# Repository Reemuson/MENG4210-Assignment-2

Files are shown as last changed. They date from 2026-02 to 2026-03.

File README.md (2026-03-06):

<p align="center" width="100%">
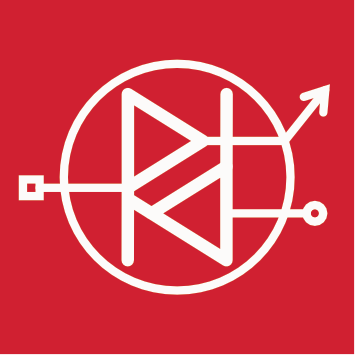
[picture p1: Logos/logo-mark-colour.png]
  
</p>

<h1 align="center">INPUT PROTECTION</h1>

<p align="center" width="100%">
  <a href="https://github.com/Reemuson/MENG4210-Assignment-2/actions/workflows/ci.yaml">
    
  </a>
</p>

<p align="center" width="100%">
    
</p>

***

<p align="center">
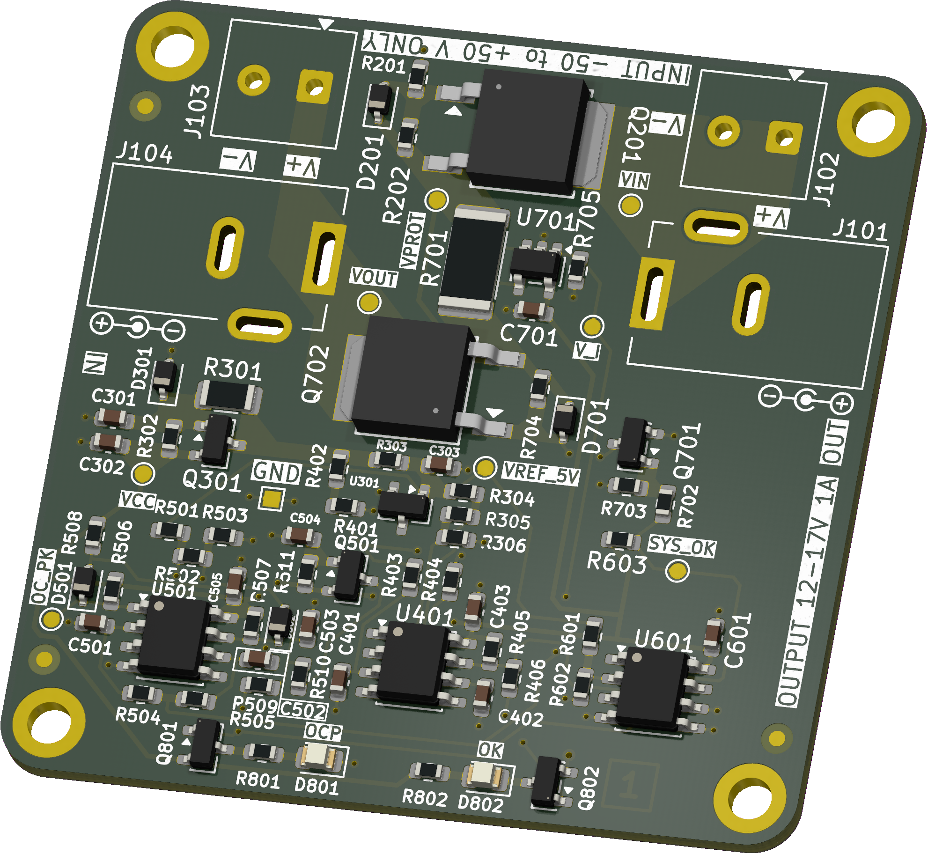
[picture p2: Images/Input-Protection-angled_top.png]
3D Top Angled
  
&nbsp; &nbsp; &nbsp; &nbsp;
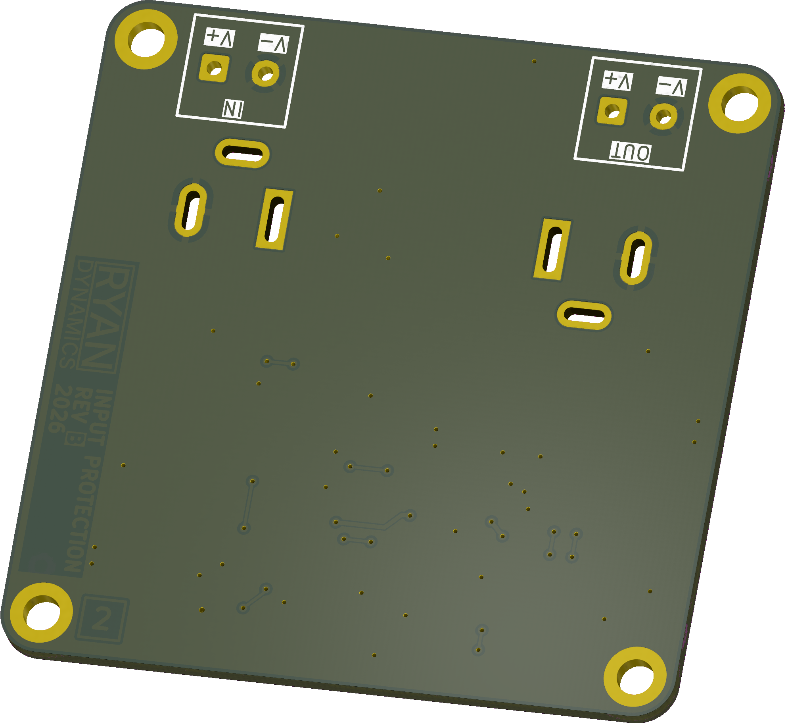
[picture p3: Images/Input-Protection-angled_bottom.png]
3D Bottom Angled
  
</p>

***

## SPECIFICATIONS

| Parameter | Value | 
| --- | --- |
| Dimensions | 50.0 × 50.0 mm |

***

## DIRECTORY STRUCTURE

    .
    ├─ Computations       # Misc calculations
    ├─ HTML               # HTML files for generated webpage
    ├─ Images             # Pictures and renders
    │
    ├─ kibot_resources    # External resources for KiBot
    │  ├─ colors          # Color theme for KiCad
    │  ├─ fonts           # Fonts used in the project
    │  ├─ scripts         # External scripts used with KiBot
    │  └─ templates       # Templates for KiBot generated reports
    │
    ├─ kibot_yaml         # KiBot YAML config files
    ├─ KiRI               # KiRI (PCB diff viewer) files
    │
    ├─ lib                # KiCad footprint and symbol libraries
    │  ├─ 3d_models       # Component 3D models
    │  ├─ lib_fp          # Footprint libraries
    │  └─ lib_sym         # Symbol libraries
    │
    ├─ Logos              # Logos
    │
    ├─ Manufacturing      # Assembly and fabrication documents
    │  ├─ Assembly        # Assembly documents (BoM, pos, notes)
    │  │
    │  └─ Fabrication     # Fabrication documents (ZIP, notes)
    │     ├─ Drill Tables # CSV drill tables
    │     └─ Gerbers      # Gerbers
    │
    ├─ Report             # Reports for ERC/DRC
    ├─ Schematic          # PDF of schematic
    ├─ Templates          # Title block templates
    ├─ Testing
    │  └─ Testpoints      # Testpoints tables      
    │
    └─ Variants           # Outputs for assembly variants

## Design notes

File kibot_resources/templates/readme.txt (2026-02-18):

<p align="center" width="100%">
  
</p>

<h1 align="center">${BOARD_NAME}</h1>

<p align="center" width="100%">
  <a href="${GIT_URL}/actions/workflows/ci.yaml">
    CI Badge
  </a>
</p>

<p align="center" width="100%">
    
</p>

***

<p align="center">
  3D Top Angled
&nbsp; &nbsp; &nbsp; &nbsp;
  3D Bottom Angled
</p>

***

## SPECIFICATIONS

| Parameter | Value | 
| --- | --- |
| Dimensions | ${bb_w_mm} × ${bb_h_mm} mm |

***

## DIRECTORY STRUCTURE

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

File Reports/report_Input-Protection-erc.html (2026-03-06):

Logo

(https://github.com/INTI-CMNB/KiBot/) | ERC report for Input-Protection
| Schematic: Input-Protection Revision: 1.0.0 Date: 2026-03-06T14:02:25+0000 KiCad Version: 9.0.7 | Errors: 0 Warnings: 18 Total: 18

Sheet / (Input-Protection.kicad_sch)

Type | Description | Details
footprint_link_issues | The current configuration does not include the footprint library 'RD-Testpoints'. | @(0.5715 mm, 0.6223 mm): Symbol TP201 [TestPoint]
lib_symbol_mismatch | Symbol 'BC846' doesn't match copy in library 'Transistor_BJT' | @(1.1811 mm, 0.762 mm): Symbol Q301 [BC846]
footprint_link_issues | The current configuration does not include the footprint library 'RD-Testpoints'. | @(1.2065 mm, 0.8763 mm): Symbol TP301 [TestPoint]
footprint_link_issues | The current configuration does not include the footprint library 'RD-Testpoints'. | @(1.4859 mm, 0.762 mm): Symbol TP302 [TestPoint]
lib_symbol_mismatch | Symbol 'BC856' doesn't match copy in library 'Transistor_BJT' | @(1.6637 mm, 1.4859 mm): Symbol Q801 [BC856]
footprint_link_issues | The current configuration does not include the footprint library 'RD-Testpoints'. | @(1.0414 mm, 2.1717 mm): Symbol TP501 [TestPoint]
lib_symbol_mismatch | Symbol 'BC846' doesn't match copy in library 'Transistor_BJT' | @(1.9431 mm, 1.4859 mm): Symbol Q802 [BC846]
footprint_link_issues | The current configuration does not include the footprint library 'RD-Testpoints'. | @(2.4892 mm, 0.9525 mm): Symbol TP701 [TestPoint]
lib_symbol_mismatch | Symbol 'BC856' doesn't match copy in library 'Transistor_BJT' | @(1.5621 mm, 2.3368 mm): Symbol Q501 [BC856]
lib_symbol_mismatch | Symbol 'BC846' doesn't match copy in library 'Transistor_BJT' | @(2.6797 mm, 0.9779 mm): Symbol Q701 [BC846]
footprint_link_issues | The current configuration does not include the footprint library 'RD-Testpoints'. | @(2.794 mm, 1.397 mm): Symbol TP702 [TestPoint]
footprint_link_issues | The current configuration does not include the footprint library 'RD-Testpoints'. | @(3.4671 mm, 0.6096 mm): Symbol TP101 [TestPoint]
footprint_link_issues | The current configuration does not include the footprint library 'RD-Testpoints'. | @(3.302 mm, 1.27 mm): Symbol TP901 [TestPoint]
footprint_link_issues | The current configuration does not include the footprint library 'RD-Testpoints'. | @(3.7338 mm, 0.6096 mm): Symbol TP102 [TestPoint]
footprint_link_issues | The current configuration does not include the footprint library 'RD-Symbols-Silkscreen'. | @(3.81 mm, 1.5875 mm): Symbol ID901 [BOARD_STACKUP_MARKER]
lib_symbol_issues | The current configuration does not include the symbol library 'Ryan-Dynamics' | @(3.81 mm, 1.5875 mm): Symbol ID901 [BOARD_STACKUP_MARKER]

Sheet /SCHEMATIC/ (Schematic.kicad_sch)

Type | Description | Details
multiple_net_names | Both VPROT and SHUNT_HI are attached to the same items; VPROT will be used in the netlist | @(0.6985 mm, 0.6096 mm): Global Label 'VPROT' @(2.2606 mm, 0.6858 mm): Label 'SHUNT_HI'
multiple_net_names | Both VSUPPLY and SHUNT_LO are attached to the same items; VSUPPLY will be used in the netlist | @(2.4892 mm, 0.6096 mm): Global Label 'VSUPPLY' @(2.3368 mm, 0.6858 mm): Label 'SHUNT_LO'

Generated by KiBot (https://github.com/INTI-CMNB/KiBot/) v1.8.6

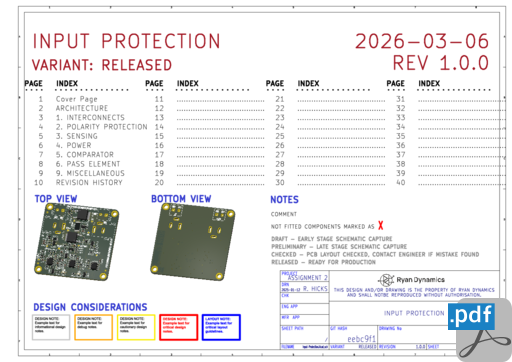
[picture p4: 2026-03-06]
HTML/images/cat_pdf_schematic_Input-Protection-schematic.png

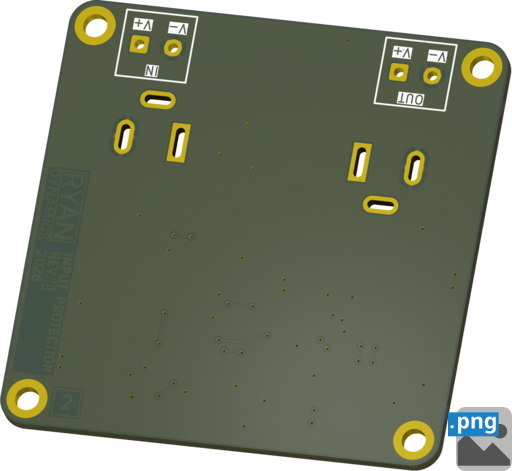
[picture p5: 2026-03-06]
HTML/images/cat_png_3d_viewer_angled_bottom_Input-Protection-angled_bottom.png

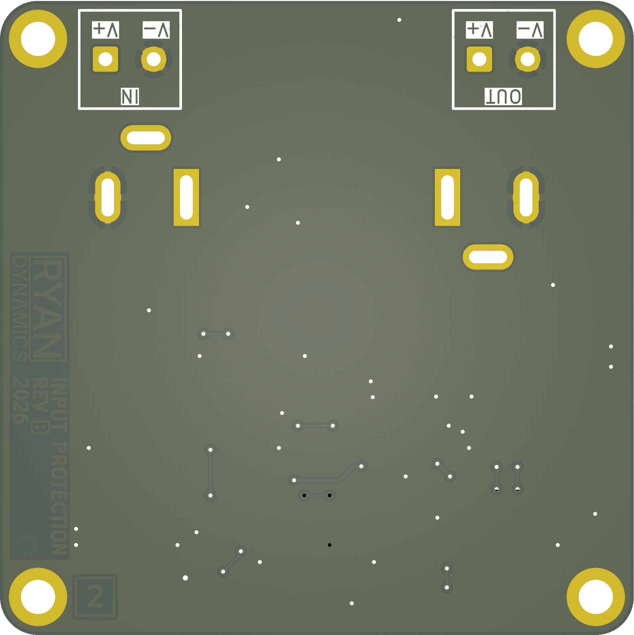
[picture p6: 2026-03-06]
Images/Input-Protection-bottom.png

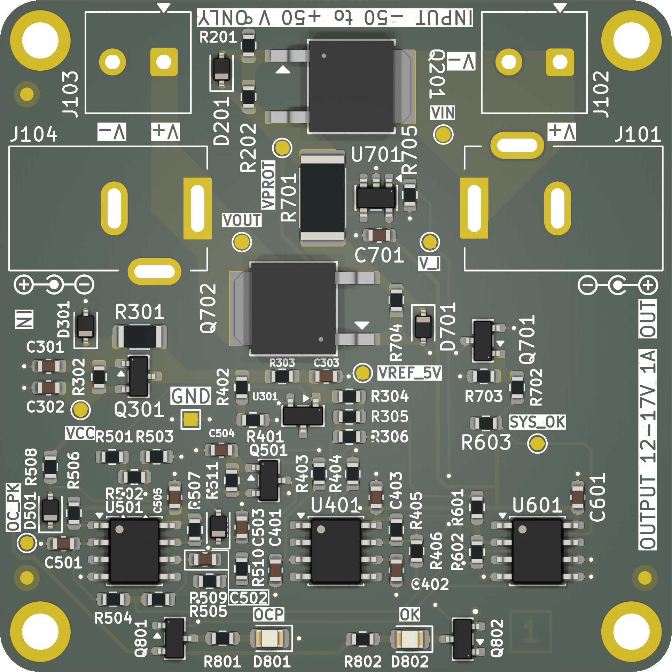
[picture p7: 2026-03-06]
Images/Input-Protection-top.png

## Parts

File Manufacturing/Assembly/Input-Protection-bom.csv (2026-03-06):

Row | Quantity Per PCB | References | Value | Datasheet | Footprint | Description | Manufacturer | MPN | Supplier | SPN | Notes
1 | 4 | C303 C401 C402 C501 | 10n | https://mm.digikey.com/Volume0/opasdata/d220001/medias/docus/931/C_Series_GeneralAppl_B11.pdf | C_0603_1608Metric | CAP CER 0.01UF 50V X7R 0603 | TPK | C1608X7R1H103KT
2 | 5 | C301 C403 C505 C601 C701 | 100n | https://mm.digikey.com/Volume0/opasdata/d220001/medias/docus/931/C_Series_GeneralAppl_B11.pdf | C_0603_1608Metric | CAP CER 0.1UF 16V X7R 0603 | TPK | C1608X7R1C104KT
3 | 3 | C302 C502 C504 | 1u | https://mm.digikey.com/Volume0/opasdata/d220001/medias/docus/931/C_Series_GeneralAppl_B11.pdf | C_0603_1608Metric | CAP CER 1UF 6.3V X7R 0603 | TPK | C1608X5R0J105KT
4 | 1 | C503 | 4.7u | https://mm.digikey.com/Volume0/opasdata/d220001/medias/docus/931/C_Series_GeneralAppl_B11.pdf | C_0603_1608Metric | CAP CER 4.7UF 6.3V X5R 0603 | TPK | C1608X5R0J475MT
5 | 2 | D501 D502 | 1N4148WS | https://diotec.com/request/datasheet/1n4148ws.pdf | D_SOD-323 | DIODE STANDARD 75V 150MA SOD323F | Diotec Semiconductor | 1N4148WS |  |  | Fast switching diode
6 | 2 | D201 D701 | D3Z10BF-7 | https://www.diodes.com/assets/Datasheets/D3ZxVxBF.pdf | D_SOD-323 | DIODE ZENER 10V 400MW SOD323F | Diodes Incorporated | D3Z10BF-7 |  |  | VZ = 10 V, suitable for input over-voltage clamping
7 | 1 | D801 | LED | https://optoelectronics.liteon.com/upload/download/DS-22-99-0150/LTST-C170KRKT.pdf | LED_0805_2012Metric | LED RED CLEAR SMD | Lite-On Inc. | LTST-C170KRKT | DigiKey | 160-1415-1-ND | Any low power red 0805 LED
8 | 1 | D802 | LED | https://optoelectronics.liteon.com/upload/download/DS22-2000-073/LTST-C170KGKT.pdf | LED_0805_2012Metric | LED RED CLEAR SMD | Lite-On Inc. | LTST-C170KGKT | DigiKey | 160-1414-1-ND | Any low power green 0805 LED
9 | 1 | D301 | MM3Z5V6 | https://www.diodes.com/assets/Datasheets/D3ZxVxBF.pdf | D_SOD-323 | DIODE ZENER 5V6 400MW SOD323F | Diotec | MM3Z5V6 |  |  | VZ = 5V6, for VCC reference
10 | 2 | J102 J103 | EBWA-02-B | https://app.adam-tech.com/products/download/data_sheet/204240/ebwa-xx-b-data-sheet.pdf | TerminalBlock_Phoenix_MKDS-1-2-3.81_1x02_P3.81mm_Horizontal | EURO BLOCK 2P | Adam Tech | EBWA-02-B
11 | 2 | J101 J104 | KLDX-0202-B | https://www.kycon.com/Catalog_PDF/KLDX_0202.pdf | BarrelJack_Kycon_KLDX-0202-xC_Horizontal | CONN PWR JACK 2.5X5.5MM SOLDER | Kycon Inc | KLDX-0202-B
12 | 3 | Q301 Q701 Q802 | BC846 | https://assets.nexperia.com/documents/data-sheet/BC846X-Q_SER.pdf | SOT-23 | TRANS NPN 65V 0.1A TO-236AB | Nexperia USA Inc. | BC846 |  |  | VCEO > 65 V for 50 V rail, IC small, used as gate pull-down switch
13 | 2 | Q501 Q801 | BC856 | https://www.onsemi.com/pub/Collateral/BC860-D.pdf | SOT-23 | 0.1A Ic, 65V Vce, PNP Transistor, SOT-23
14 | 2 | Q201 Q702 | MCU18P10Y-TP | https://www.mccsemi.com/pdf/Products/MCU18P10Y(DPAK).pdf | DPAK_MCC | MOSFET P-CH 100V 18A DPAK | MCC (Micro Commercial Components) | MCU18P10Y-TP |  |  | VDS > 100 V, ID > 2 A, P-channel device suitable for high-side switching
15 | 1 | R701 | 20m | https://www.vishay.com/docs/30100/wsl.pdf | R_2512_6332Metric | RES 0.02 OHM 1% 1W 2512 | Vishay Dale | WSL2512R0200FEA | DigiKey | WSLG-.02CT-ND | Current sense shunt, sets OCP trip (~1 A). Ideally should be <100m
16 | 4 | R403 R404 R504 R510 | 1k | https://www.analogtechnologies.com/document/New_Resistor_Kits.pdf | R_0603_1608Metric | RES 1K OHM 1% 1/10W 0603 | Analog Technologies
17 | 2 | R801 R802 | 2.49k | https://www.analogtechnologies.com/document/New_Resistor_Kits.pdf | R_0603_1608Metric | RES 2.49K OHM 1% 1/10W 0603 | Analog Technologies
18 | 5 | R405 R506 R507 R603 R702 | 10k | https://www.analogtechnologies.com/document/New_Resistor_Kits.pdf | R_0603_1608Metric | RES 10K OHM 1% 1/10W 0603 | Analog Technologies
19 | 1 | R301 | 12.1k | https://www.analogtechnologies.com/document/New_Resistor_Kits.pdf | R_1206_3216Metric | RES 12.1K OHM 1% 1/4W 1206 | Analog Technologies
20 | 1 | R705 | 15k | https://www.analogtechnologies.com/document/New_Resistor_Kits.pdf | R_0603_1608Metric | RES 15K OHM 1% 1/10W 0603 | Analog Technologies
21 | 1 | R601 | 18.2k | https://www.analogtechnologies.com/document/New_Resistor_Kits.pdf | R_0603_1608Metric | RES 18.2K OHM 1% 1/10W 0603 | Analog Technologies
22 | 1 | R401 | 22.1k | https://www.analogtechnologies.com/document/New_Resistor_Kits.pdf | R_0603_1608Metric | RES 22.1K OHM 1% 1/10W 0603 | Analog Technologies
23 | 1 | R503 | 30.1k | https://www.analogtechnologies.com/document/New_Resistor_Kits.pdf | R_0603_1608Metric | RES 30.1K OHM 1% 1/10W 0603 | Analog Technologies
24 | 2 | R303 R602 | 33.2k | https://www.analogtechnologies.com/document/New_Resistor_Kits.pdf | R_0603_1608Metric | RES 33.2K OHM 1% 1/10W 0603 | Analog Technologies
25 | 2 | R305 R505 | 49.9k | https://www.analogtechnologies.com/document/New_Resistor_Kits.pdf | R_0603_1608Metric | RES 49.9K OHM 1% 1/10W 0603 | Analog Technologies
26 | 8 | R201 R202 R302 R406 R509 R511 R703 R704 | 100k | https://www.analogtechnologies.com/document/New_Resistor_Kits.pdf | R_0603_1608Metric | RES 100K OHM 1% 1/10W 0603 | Analog Technologies
27 | 2 | R306 R502 | 121k | https://www.analogtechnologies.com/document/New_Resistor_Kits.pdf | R_0603_1608Metric | RES 121K OHM 1% 1/10W 0603 | Analog Technologies
28 | 1 | R402 | 200k | https://www.analogtechnologies.com/document/New_Resistor_Kits.pdf | R_0603_1608Metric | RES 200K OHM 1% 1/10W 0603 | Analog Technologies
29 | 1 | R304 | 332k | https://www.analogtechnologies.com/document/New_Resistor_Kits.pdf | R_0603_1608Metric | RES 332K OHM 1% 1/10W 0603 | Analog Technologies
30 | 1 | R501 | 357k | https://www.analogtechnologies.com/document/New_Resistor_Kits.pdf | R_0603_1608Metric | RES 357K OHM 1% 1/10W 0603 | Analog Technologies
31 | 1 | R508 | 432k | https://www.analogtechnologies.com/document/New_Resistor_Kits.pdf | R_0603_1608Metric | RES 432K OHM 1% 1/10W 0603 | Analog Technologies
32 | 1 | U701 | INA169NA/3K | http://www.ti.com/lit/ds/symlink/ina169.pdf | SOT-23-5 | IC CURRENT MONITOR 0.5% SOT23-5 | Texas Instruments | INA169NA/3K |  |  | Transconductance of 1mA/V
33 | 3 | U401 U501 U601 | LM393 | http://www.ti.com/lit/ds/symlink/lm393.pdf | SOIC-8_3.9x4.9mm_P1.27mm | Low-Power, Low-Offset Voltage, Dual Comparators, DIP-8/SOIC-8/TO-99-8
34 | 1 | U301 | LM4040N-5.0 | http://www.ti.com/lit/ds/symlink/lm4040-n.pdf | SOT-23 | IC VREF SHUNT 0.5% SOT23-3 | Texas Instruments | LM4040CIM3-5.0/NOPB |  |  | VREF = 5.0 V, low temperature coefficient, suitable for precision threshold VREF

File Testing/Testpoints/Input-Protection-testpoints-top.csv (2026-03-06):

Ref. | Net | X [mm] | Y [mm]
TP101 | VIN | 33.00 | 40.00
TP102 | VOUT | 18.00 | 32.00
TP201 | VPROT | 21.00 | 39.00
TP301 | VCC | 6.00 | 19.50
TP302 | VREF_5V | 27.00 | 22.25
TP501 | OC_PEAK_FAULT | 2.00 | 9.60
TP701 | SYS_OK | 40.00 | 17.00
TP702 | V_I | 32.00 | 32.00
TP901 | GND | 14.20 | 18.80

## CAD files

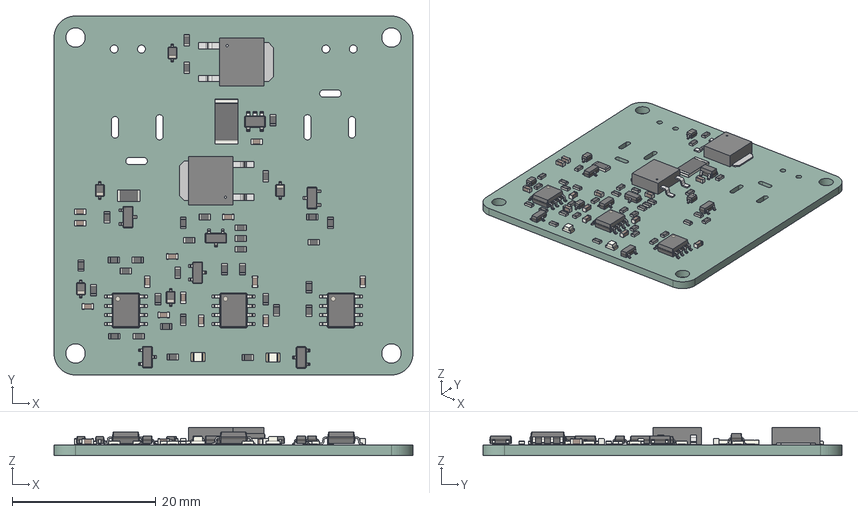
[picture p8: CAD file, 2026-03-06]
3D/Input-Protection.step
50.0 x 50.0 x 3.96 mm
R_0603_1608Metric x 33
C_0603_1608Metric x 13
D_SOD-323 x 5
SOT-23 x 6
R_1206_3216Metric
DPAK_MCC x 2
SOIC-8_3.9x4.9mm_P1.27mm x 3
LED_0805_2012Metric x 2
R_2512_6332Metric
SOT-23-5
kibot_4t420ams_PCB

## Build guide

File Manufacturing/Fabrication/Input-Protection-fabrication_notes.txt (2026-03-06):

FABRICATION NOTES (UNLESS OTHERWISE SPECIFIED)

1)	FABRICATE PER IPC-6012A CLASS 2.

2)	OUTLINE DEFINED IN SEPARATE GERBER FILE WITH
	"Edge_Cuts.GBR" SUFFIX.

3)	SEE SEPARATE DRILL FILES WITH ".DRL" SUFFIX 
	FOR HOLE LOCATIONS.

4)	SURFACE FINISH: ENIG

5)	SOLDERMASK ON BOTH SIDES OF THE BOARD SHALL 
	BE LPI, COLOR GREEN.

6)	SILK SCREEN LEGEND TO BE APPLIED PER LAYER 
	STACKUP USING WHITE NON-CONDUCTIVE EPOXY INK.

7)	VENDOR SHOULD FOLLOW ROHS COMPLIANT PROCESS 
	AND Pb FREE FOR MANUFACTURING

8)	PCB MATERIAL REQUIREMENTS:

	A.	FLAMMABILITY RATING MUST MEET OR EXCEED 
		UL94V-0 REQUIREMENTS.
	B.	Tg 170 C OR EQUIVALENT.
	C.	EQUIVALENT MATERIAL SHALL BE RoHS COMPLIANT, 
		HALOGEN FREE AND APPROVED BY RYAN DYNAMICS.

9)	DESIGN GEOMETRY MINIMUM FEATURE SIZES:

	BOARD SIZE			50.000 × 50.000 mm
	BOARD THICKNESS		1.590 mm
	TRACE WIDTH			0.200 mm
	TRACE TO TRACE		0.200 mm
	MIN. HOLE (PTH)		0.300 mm
	MIN. HOLE (NPTH)	N/A mm
	ANNULAR RING		0.150 mm
	COPPER TO HOLE		0.254 mm
	COPPER TO EDGE		0.250 mm
	HOLE TO HOLE		0.254 mm

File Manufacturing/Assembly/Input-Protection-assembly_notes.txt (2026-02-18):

ASSEMBLY NOTES (UNLESS OTHERWISE SPECIFIED)

1)	DO NOT POPULATE PARTS ARE MARKED WITH A RED CROSS.

2)	DO NOT POPULATE PARTS ARE NOT PRESENT IN THE BOM.

3)	IF CONFLICTING INFORMATION IS FOUND BETWEEN THE ASSEMBLY
	FILE AND BOM, BOM SHOULD BE USED AS THE MAIN SOURCE.

4)	CONFORMAL COATING IS NOT REQUIRED.

5)	DOT IDENTIFIES PIN #1 LOCATION AND DEVICE ORIENTATION
	WHEN VIEWED FROM THE TOP.

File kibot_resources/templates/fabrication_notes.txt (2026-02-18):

FABRICATION NOTES (UNLESS OTHERWISE SPECIFIED)

1)	FABRICATE PER IPC-6012A CLASS 2.

2)	OUTLINE DEFINED IN SEPARATE GERBER FILE WITH
	"Edge_Cuts.GBR" SUFFIX.

3)	SEE SEPARATE DRILL FILES WITH ".DRL" SUFFIX 
	FOR HOLE LOCATIONS.

4)	SURFACE FINISH: ${pcb_finish_cap}

5)	SOLDERMASK ON BOTH SIDES OF THE BOARD SHALL 
	BE LPI, COLOR ${solder_mask_color_text_cap}.

6)	SILK SCREEN LEGEND TO BE APPLIED PER LAYER 
	STACKUP USING ${silk_screen_color_text_cap} NON-CONDUCTIVE EPOXY INK.

7)	VENDOR SHOULD FOLLOW ROHS COMPLIANT PROCESS 
	AND Pb FREE FOR MANUFACTURING

8)	PCB MATERIAL REQUIREMENTS:

	A.	FLAMMABILITY RATING MUST MEET OR EXCEED 
		UL94V-0 REQUIREMENTS.
	B.	Tg 170 C OR EQUIVALENT.
	C.	EQUIVALENT MATERIAL SHALL BE RoHS COMPLIANT, 
		HALOGEN FREE AND APPROVED BY ${COMPANY_cap}.

9)	DESIGN GEOMETRY MINIMUM FEATURE SIZES:

	BOARD SIZE			${bb_w_mm} × ${bb_h_mm} mm
	BOARD THICKNESS		${thickness_mm} mm
	TRACE WIDTH			${track_mm} mm
	TRACE TO TRACE		${clearance_mm} mm
	MIN. HOLE (PTH)		${drill_pth_real_mm} mm
	MIN. HOLE (NPTH)	${drill_npth_real_mm} mm
	ANNULAR RING		${oar_mm} mm
	COPPER TO HOLE		${c2h_mm} mm
	COPPER TO EDGE		${c2e_mm} mm
	HOLE TO HOLE		${h2h_mm} mm
#?stackup and impedance_controlled

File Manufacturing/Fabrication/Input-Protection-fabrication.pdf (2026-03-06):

# TOP FABRICATION (SCALE 1:1)

# INPUT PROTECTION FABRICATION DOCUMENT

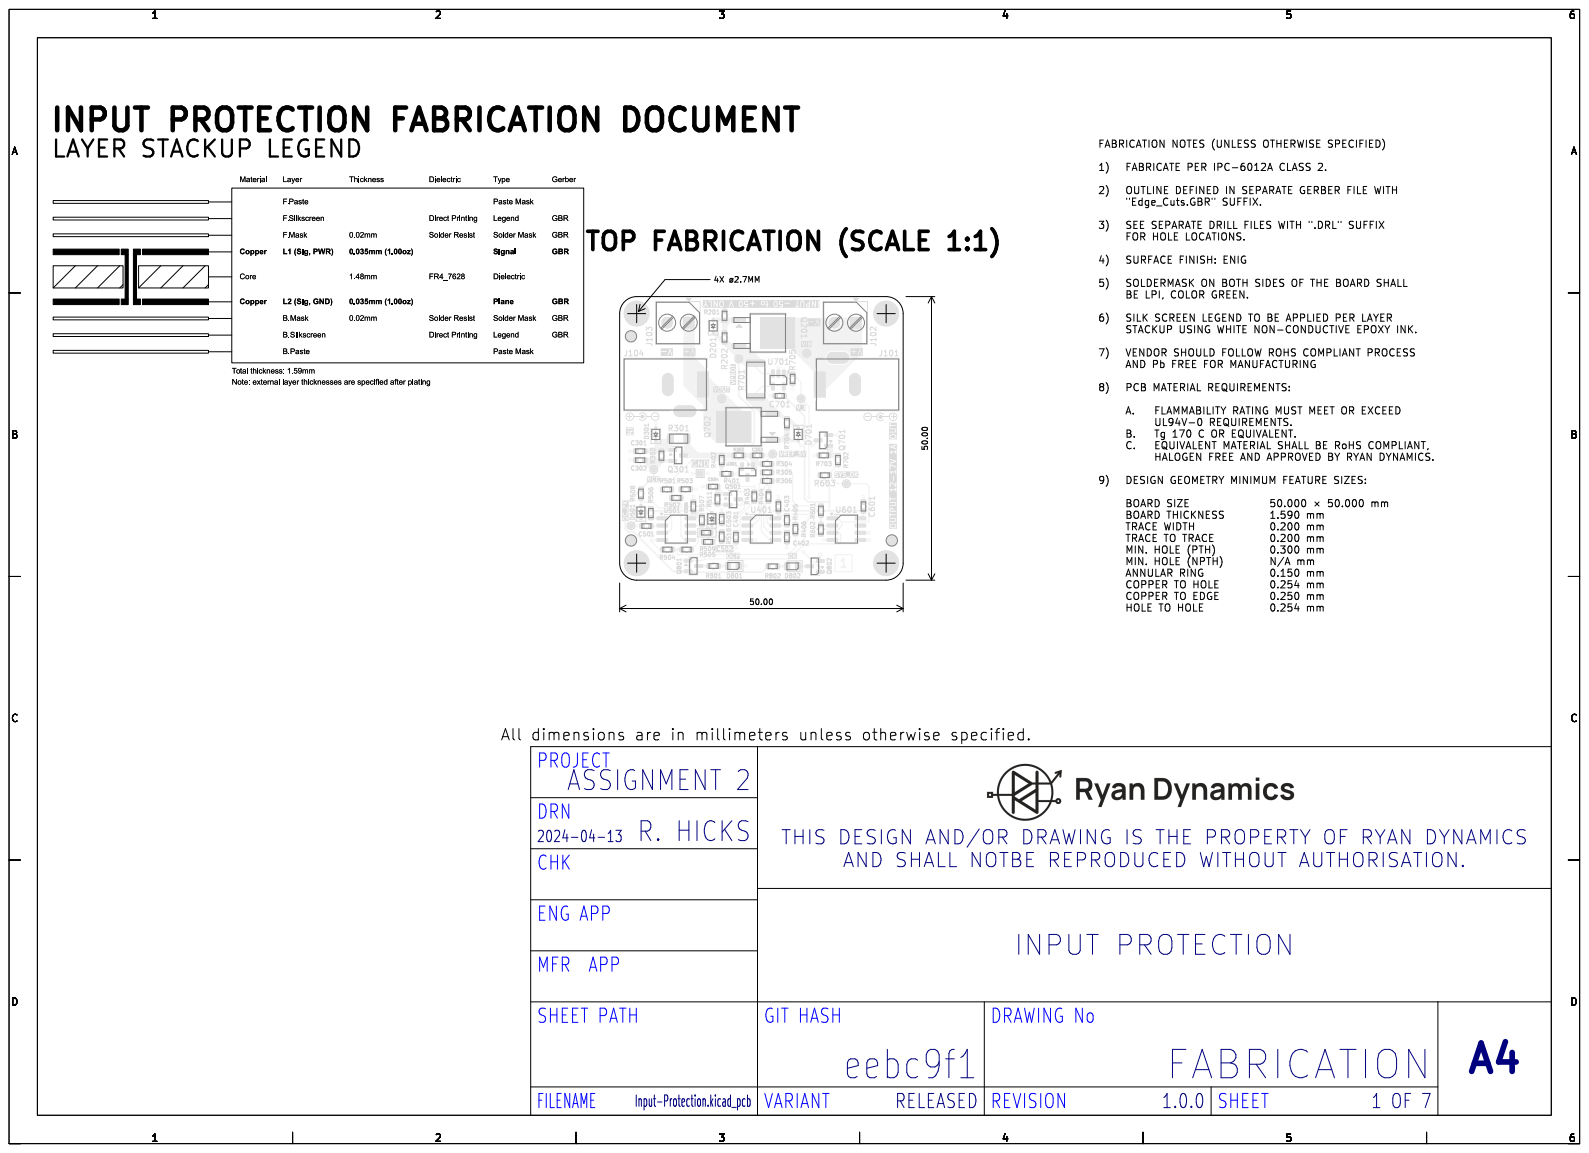
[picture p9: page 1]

FABRICATION NOTES (UNLESS OTHERWISE SPECIFIED)

1) FABRICATE PER IPC-6012A CLASS 2.

2) OUTLINE DEFINED IN SEPARATE GERBER FILE WITH
"Edge_Cuts.GBR" SUFFIX.

3) SEE SEPARATE DRILL FILES WITH ".DRL" SUFFIX
FOR HOLE LOCATIONS.

5) SOLDERMASK ON BOTH SIDES OF THE BOARD SHALL
BE LPI, COLOR GREEN.

6) SILK SCREEN LEGEND TO BE APPLIED PER LAYER
STACKUP USING WHITE NON-CONDUCTIVE EPOXY INK.

7) VENDOR SHOULD FOLLOW ROHS COMPLIANT PROCESS
AND Pb FREE FOR MANUFACTURING

A. FLAMMABILITY RATING MUST MEET OR EXCEED
UL94V-0 REQUIREMENTS.
B. Tg 170 C OR EQUIVALENT.
C. EQUIVALENT MATERIAL SHALL BE RoHS COMPLIANT,
HALOGEN FREE AND APPROVED BY RYAN DYNAMICS.

9) DESIGN GEOMETRY MINIMUM FEATURE SIZES:

BOARD SIZE 50.000 × 50.000 mm
BOARD THICKNESS 1.590 mm
TRACE WIDTH 0.200 mm
TRACE TO TRACE 0.200 mm
MIN. HOLE (PTH) 0.300 mm
MIN. HOLE (NPTH) N/A mm
ANNULAR RING 0.150 mm
COPPER TO HOLE 0.254 mm
COPPER TO EDGE 0.250 mm
HOLE TO HOLE 0.254 mm

All dimensions are in millimeters unless otherwise specified.
PROJECT
ASSIGNMENT 2
DRN
THIS DESIGN AND/OR DRAWING IS THE PROPERTY OF RYAN DYNAMICSAND SHALL NOTBE REPRODUCED WITHOUT AUTHORISATION.
CHK

BOTTOM | FABRICATION | (SCALE | 1:1)
INPUT | PROTECTION | FABRICATION DOCUMENT

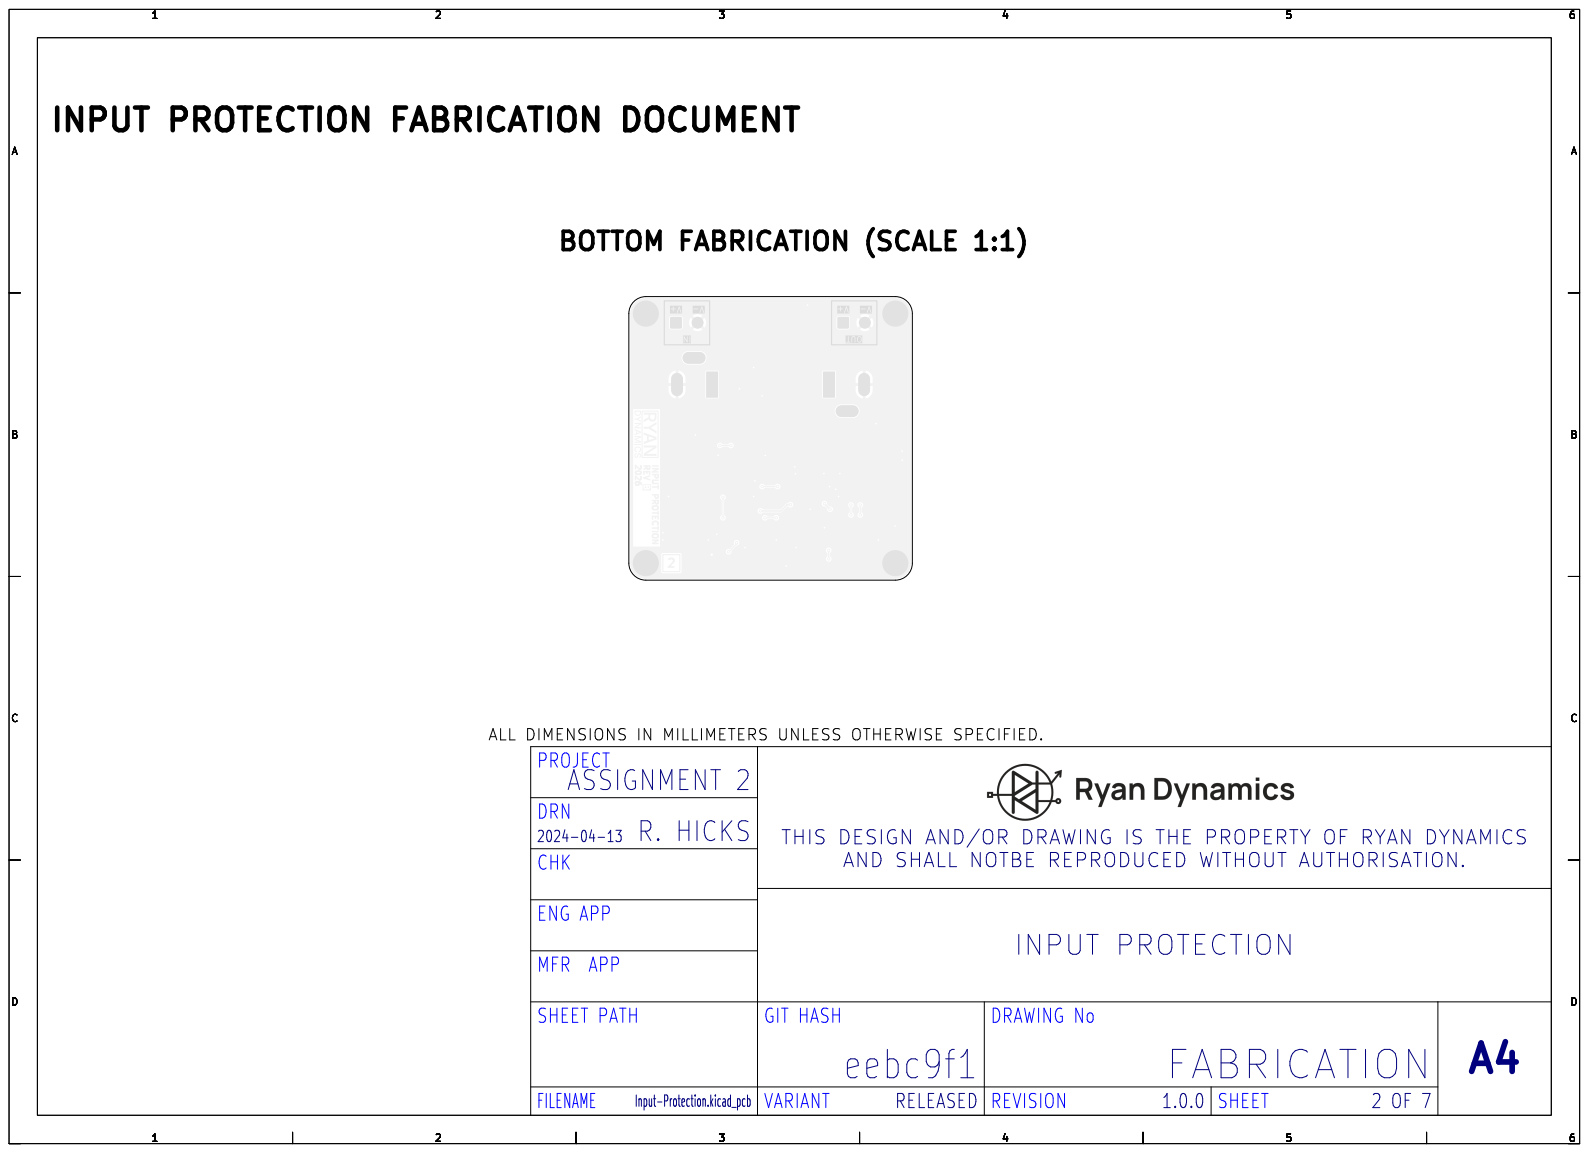
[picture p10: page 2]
DRAWING No; ASSIGNMENT 2; FABRICATION; PROJECT; INPUT; PROTECTION; ENG APP; 2024-04-13 CHK; GIT; HASH; SHEET; PATH; MFR; APP; DRN; R. HICKS; eebc9f1; THIS DESIGN AND/OR; DRAWING IS THE PROPERTY OF RYAN DYNAMICSAND SHALL NOTBE REPRODUCED WITHOUT AUTHORISATION.; ALL; DIMENSIONS; MILLIMETERS; UNLESS OTHERWISE; SPECIFIED.; REV; INPUT PROTECTION

DRILL | DRAWING L1 - L2 (SCALE | 1:1)
INPUT | PROTECTION | FABRICATION DOCUMENT

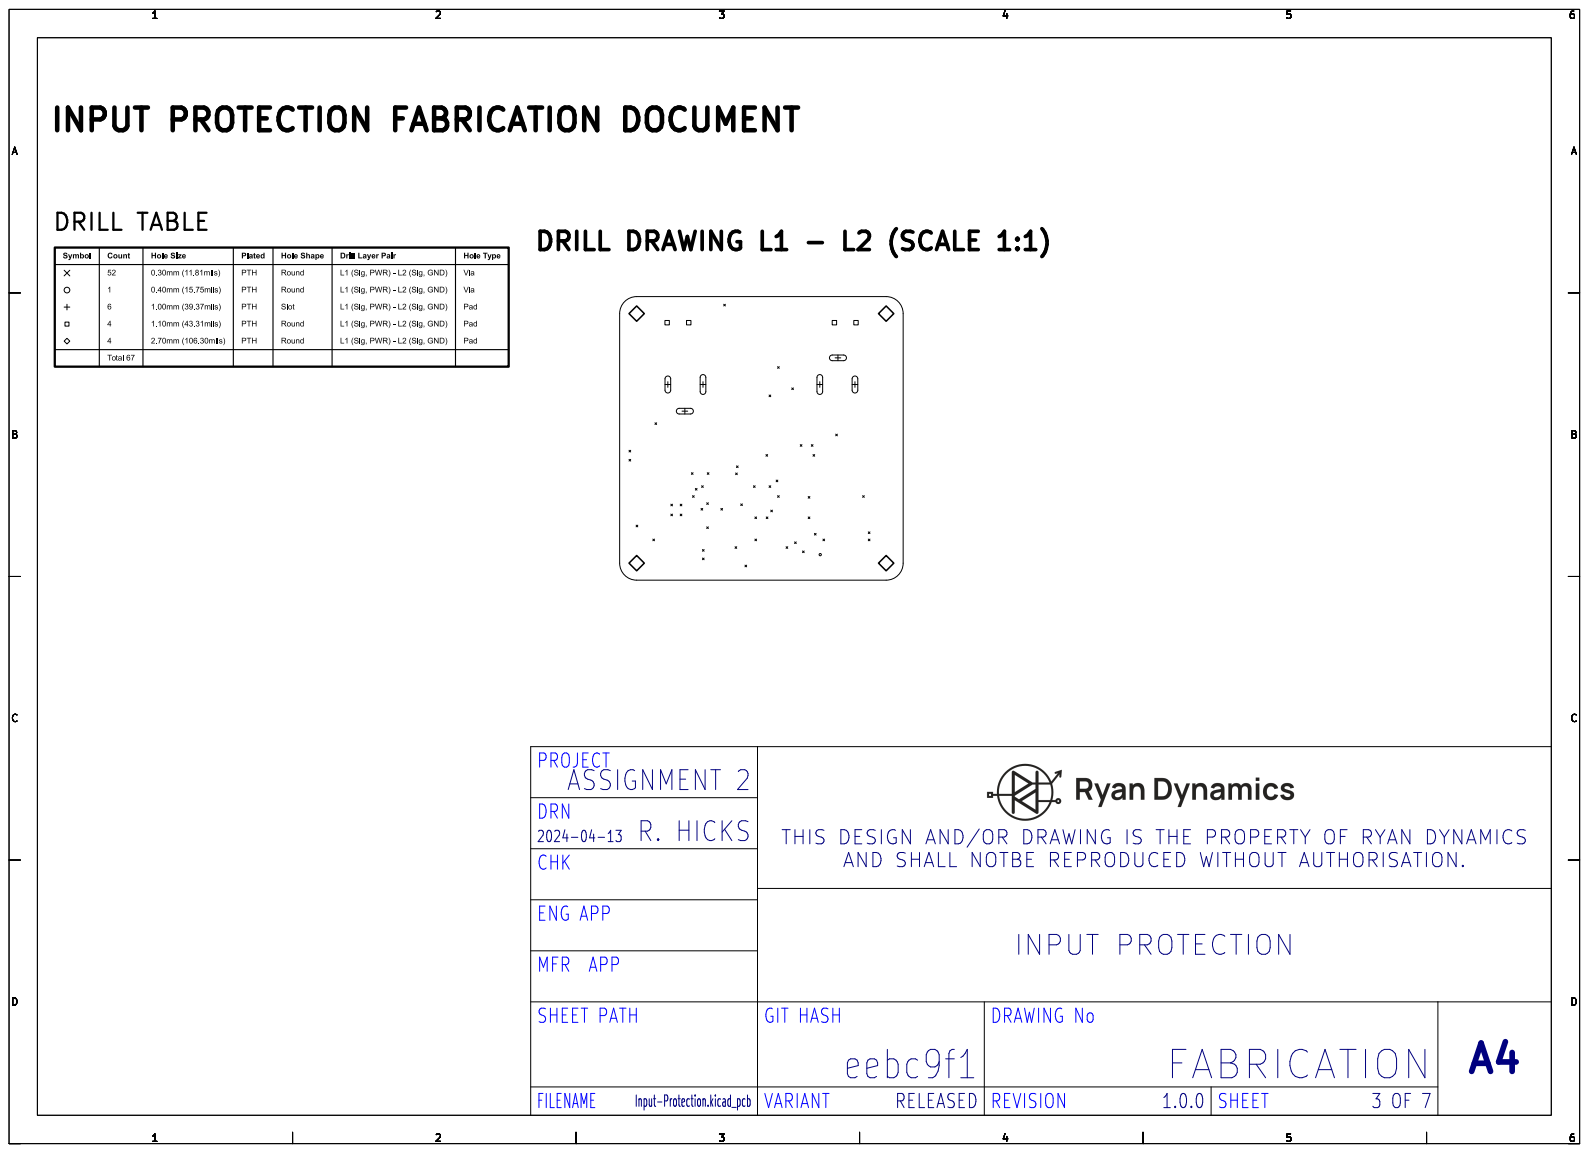
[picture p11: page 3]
DRAWING No; ASSIGNMENT 2; FABRICATION; PROJECT; INPUT; PROTECTION; ENG APP; 2024-04-13 CHK; GIT; HASH; SHEET; PATH; MFR; APP; DRN; R. HICKS; eebc9f1; THIS DESIGN AND/OR; DRAWING IS THE PROPERTY OF RYAN DYNAMICSAND SHALL NOTBE REPRODUCED WITHOUT AUTHORISATION.; DRILL TABLE

# TOP TEST POINTS (SCALE 1:1)

# INPUT PROTECTION FABRICATION DOCUMENT

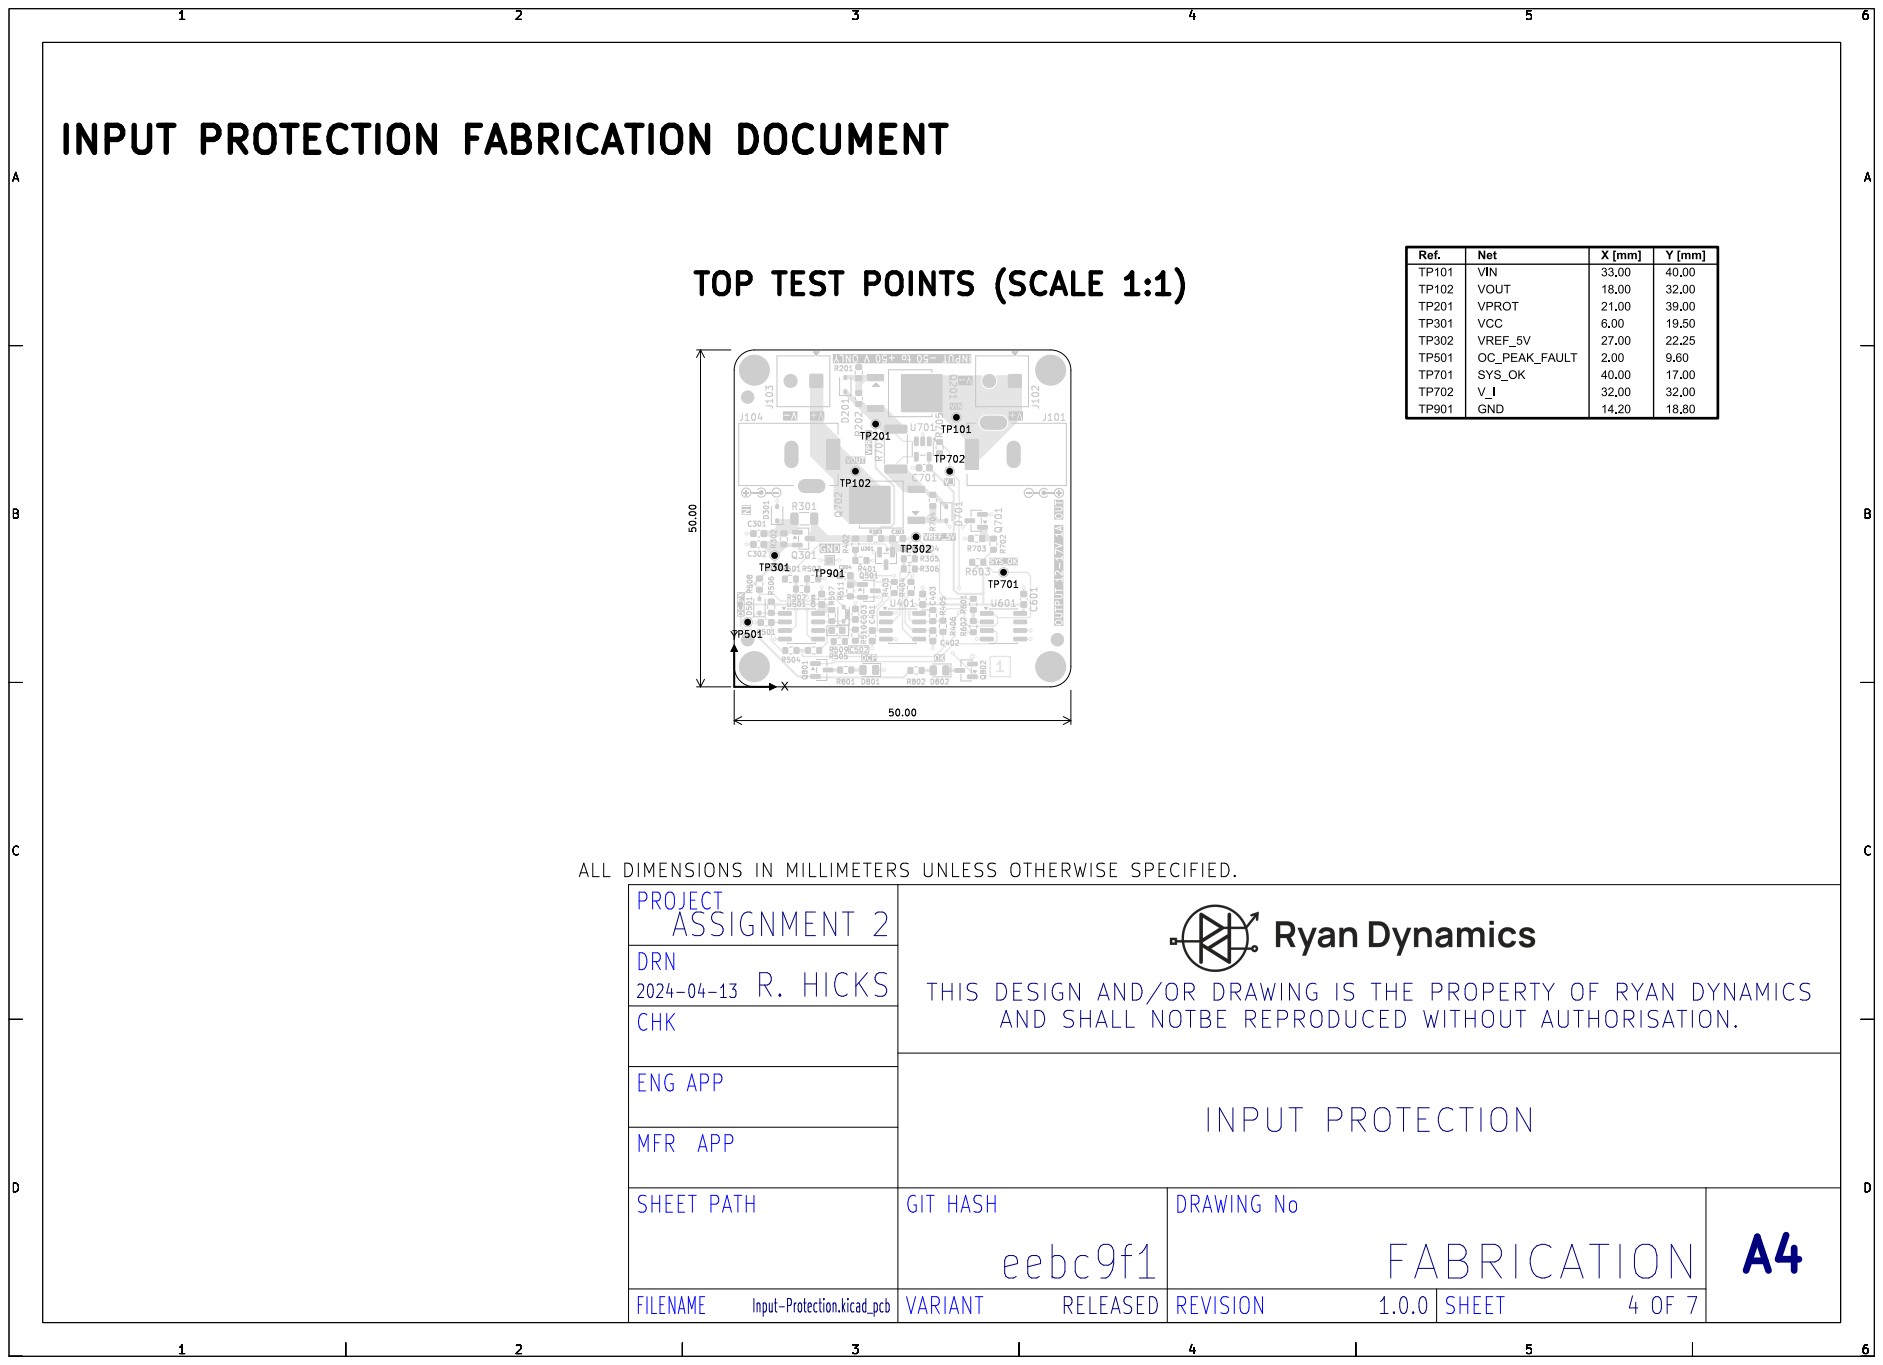
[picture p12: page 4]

PROJECT
ASSIGNMENT 2
DRN
THIS DESIGN AND/OR DRAWING IS THE PROPERTY OF RYAN DYNAMICSAND SHALL NOTBE REPRODUCED WITHOUT AUTHORISATION.
CHK

BOTTOM | TEST POINTS (SCALE | 1:1)
INPUT | PROTECTION | FABRICATION DOCUMENT

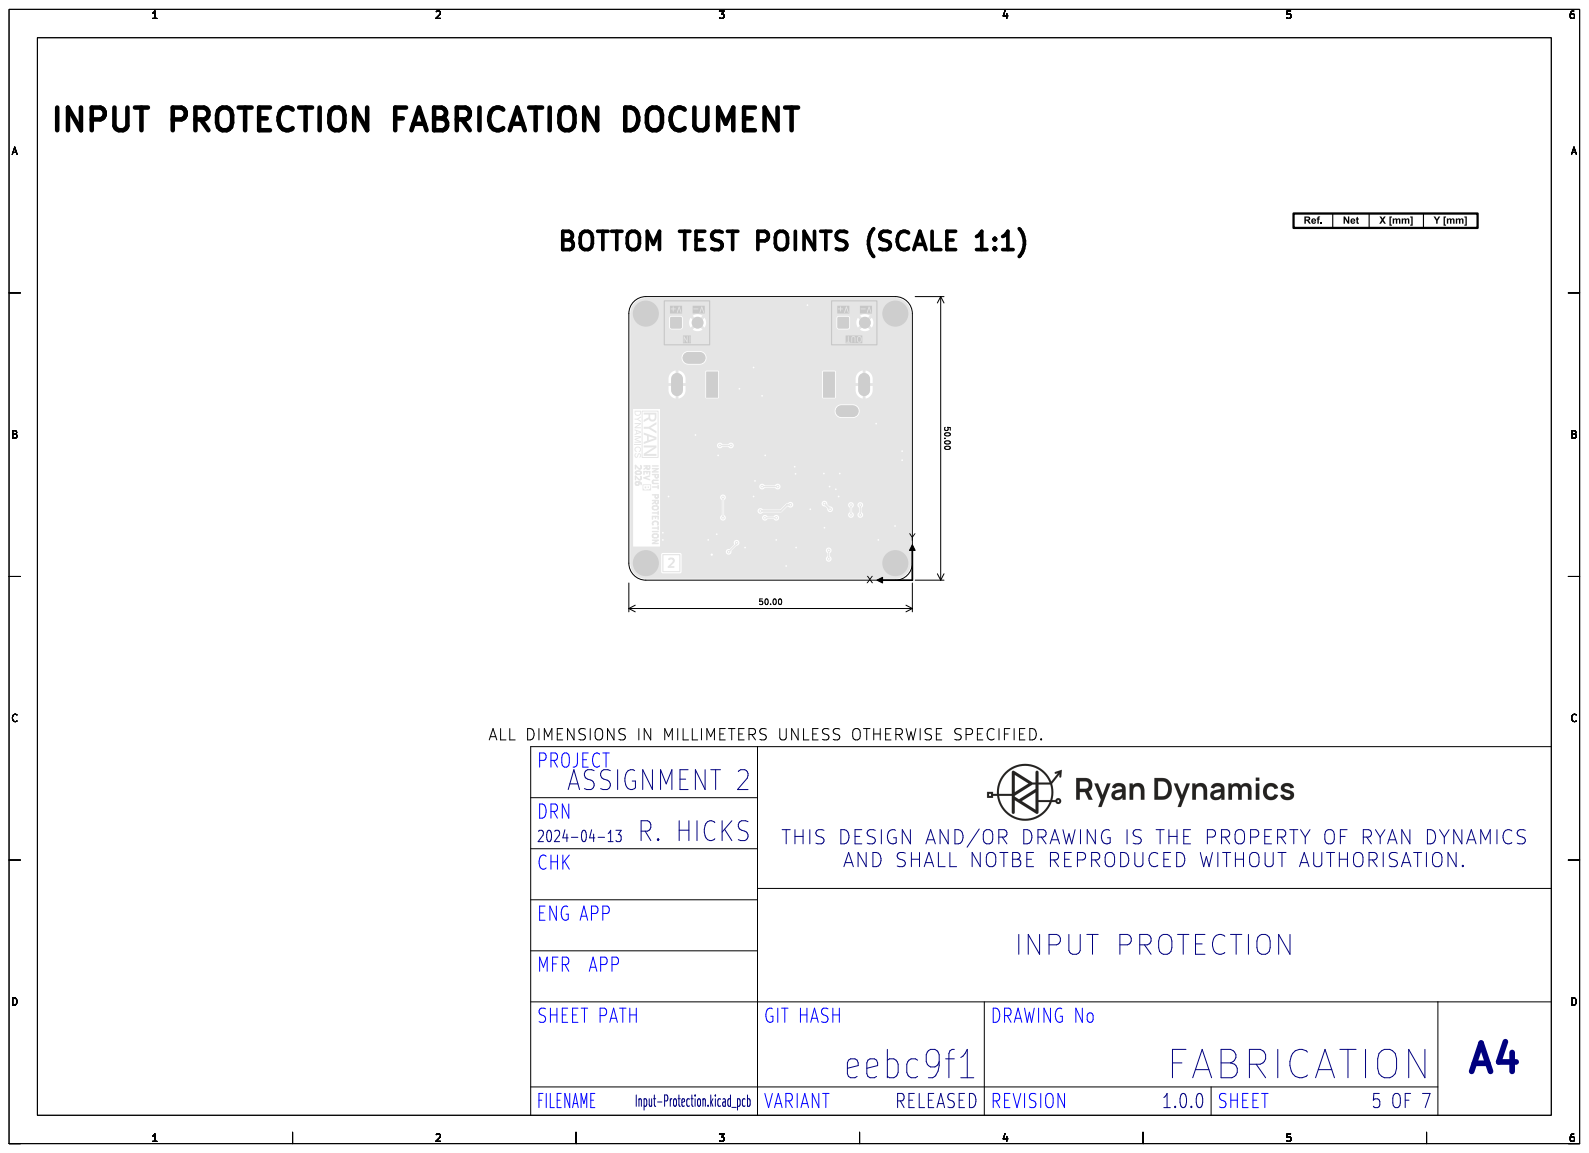
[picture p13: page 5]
DRAWING No; ASSIGNMENT 2; FABRICATION; PROJECT; INPUT; PROTECTION; ENG APP; 2024-04-13 CHK; GIT; HASH; SHEET; PATH; MFR; APP; DRN; R. HICKS; eebc9f1; THIS DESIGN AND/OR; DRAWING IS THE PROPERTY OF RYAN DYNAMICSAND SHALL NOTBE REPRODUCED WITHOUT AUTHORISATION.; ALL; DIMENSIONS; MILLIMETERS; UNLESS OTHERWISE; SPECIFIED.; REV; INPUT PROTECTION

L1 (Sig, | PWR) (SCALE 1:1)
INPUT | PROTECTION | FABRICATION DOCUMENT

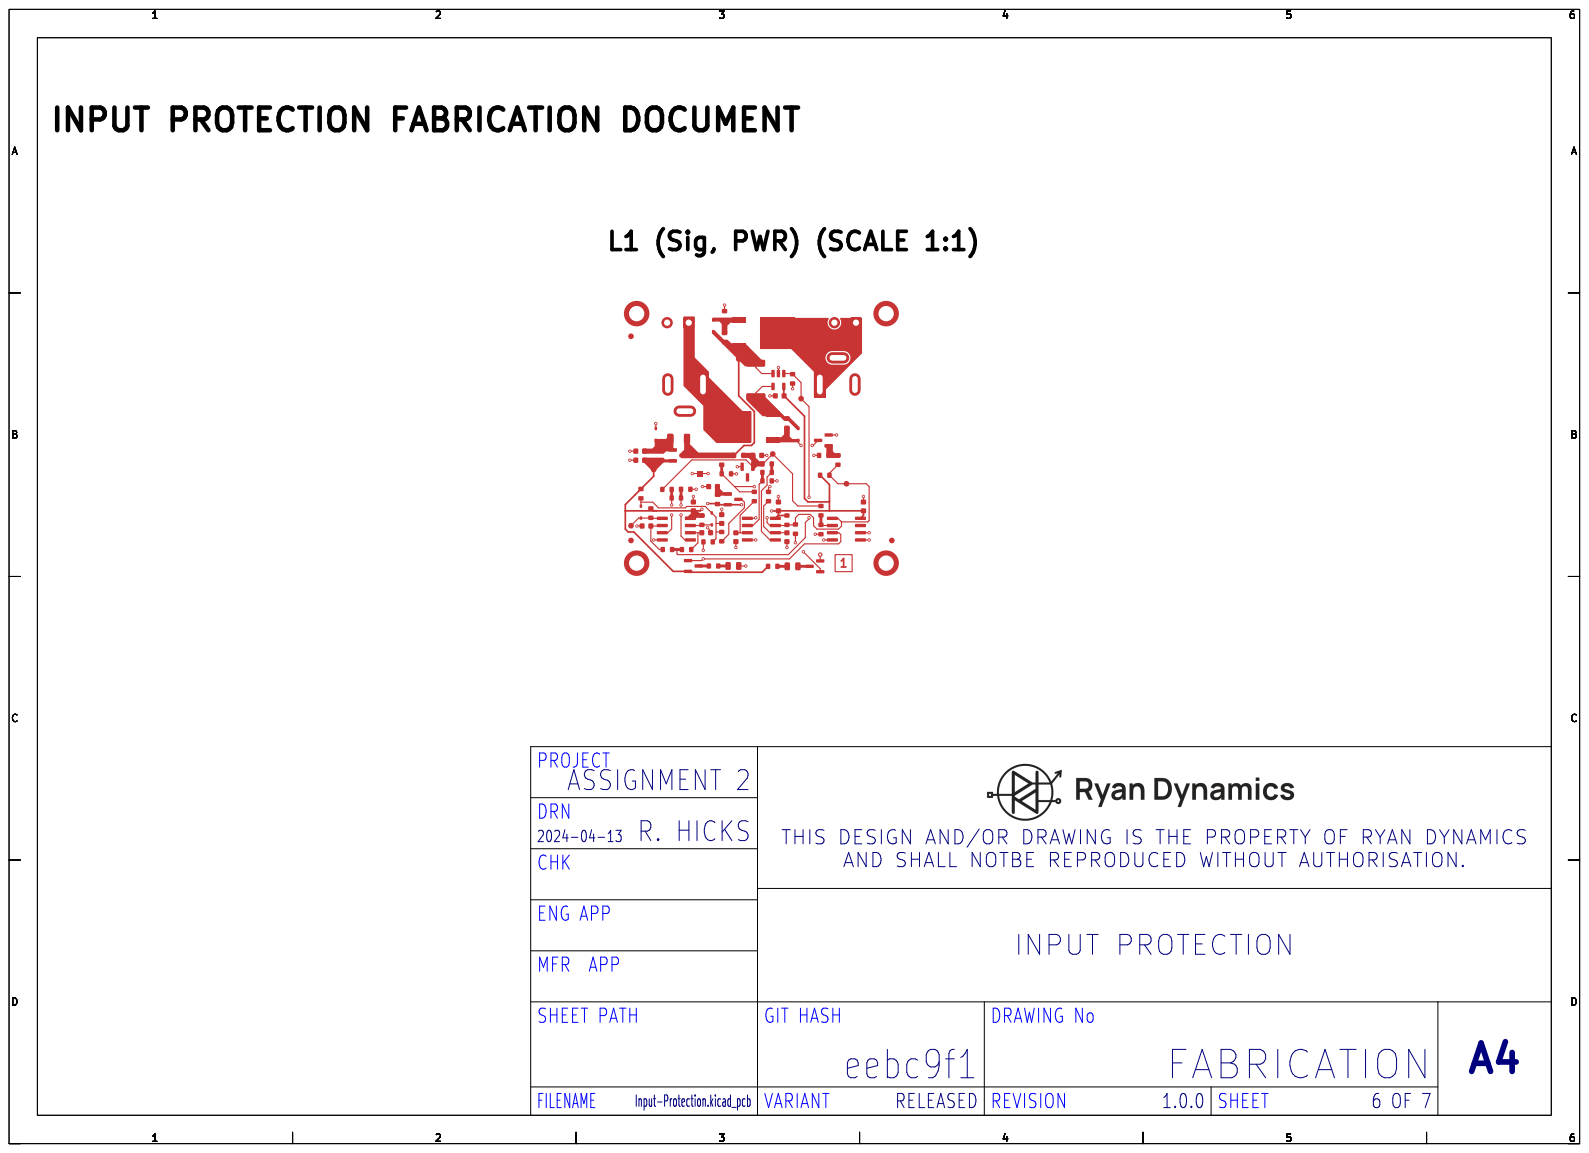
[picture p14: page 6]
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

# L2 (Sig, GND) (SCALE 1:1)

INPUT | PROTECTION | FABRICATION DOCUMENT

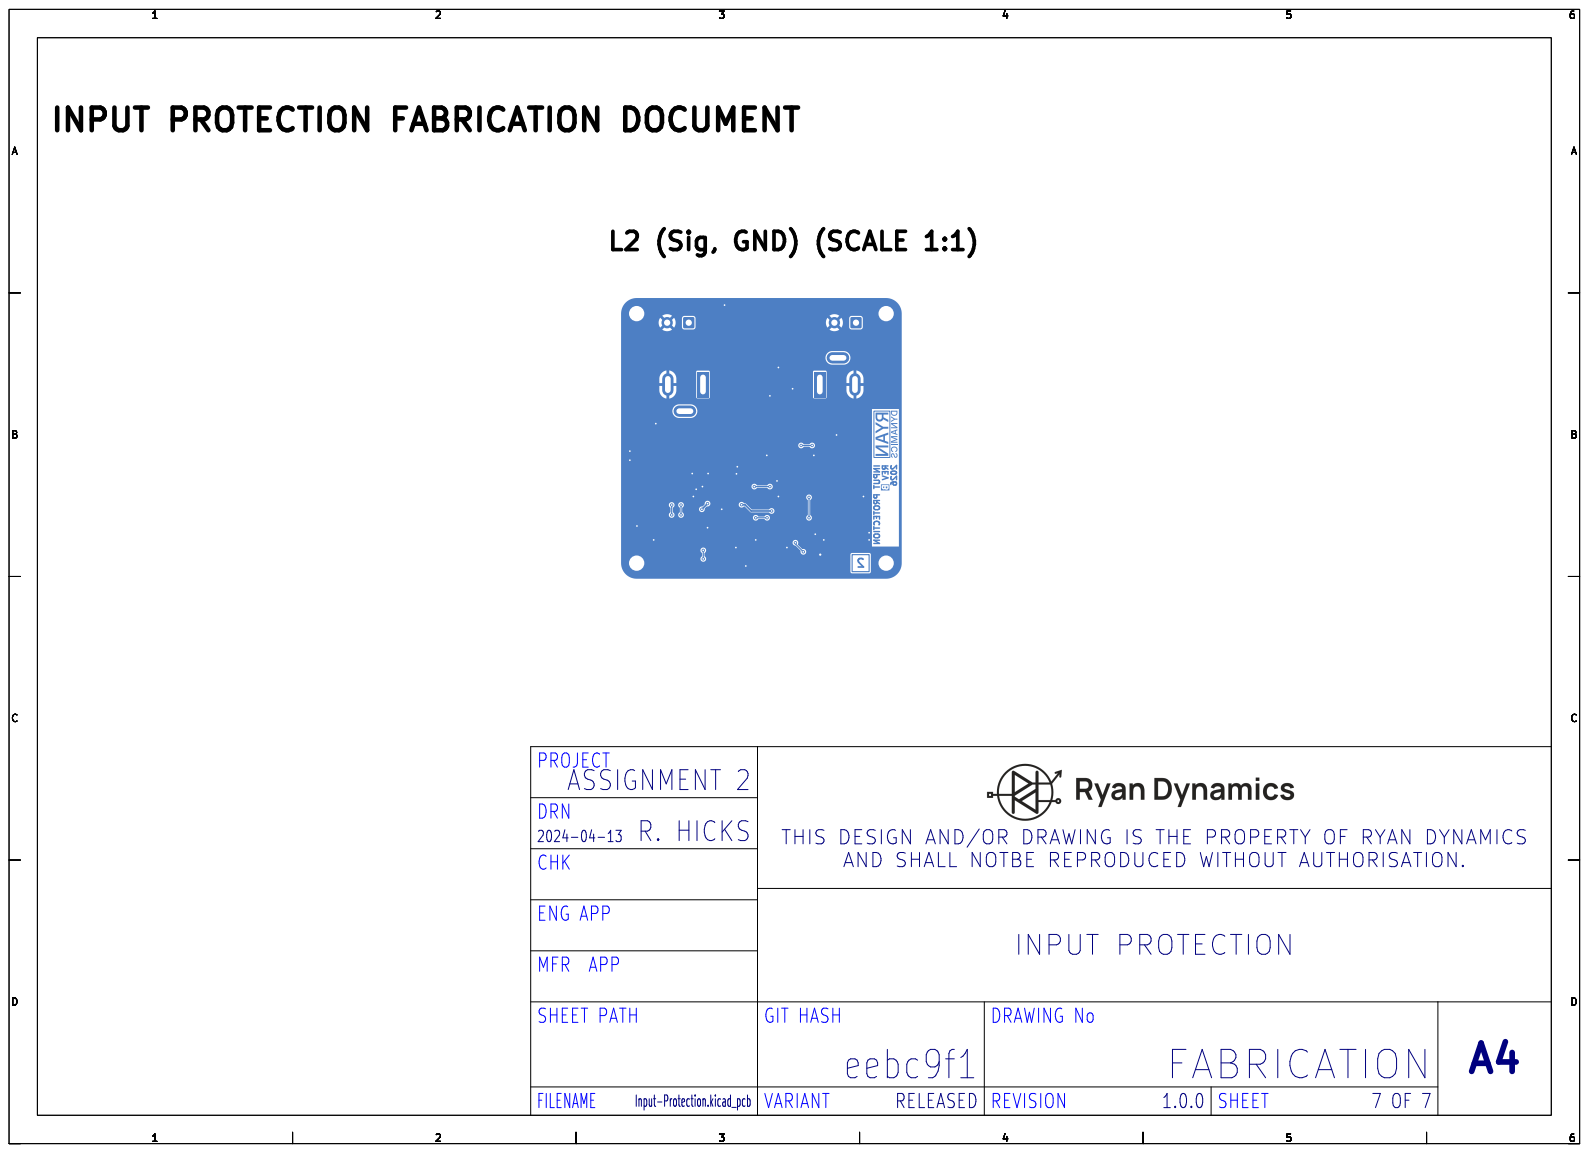
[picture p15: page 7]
DRAWING No; ASSIGNMENT 2; FABRICATION; PROJECT; INPUT; PROTECTION; ENG APP; 2024-04-13 CHK; GIT; HASH; SHEET; PATH; MFR; APP; DRN; R. HICKS; eebc9f1; THIS DESIGN AND/OR; DRAWING IS THE PROPERTY OF RYAN DYNAMICSAND SHALL NOTBE REPRODUCED WITHOUT AUTHORISATION.; INPUT PROTECTION; REV

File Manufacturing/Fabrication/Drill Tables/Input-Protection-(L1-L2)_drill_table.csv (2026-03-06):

Count | Hole Size | Plated | Hole Shape | Drill Layer Pair | Hole Type
52 | 0.30mm (11.81mils) | PTH | Round | L1 (Sig, PWR) - L2 (Sig, GND) | Via
1 | 0.40mm (15.75mils) | PTH | Round | L1 (Sig, PWR) - L2 (Sig, GND) | Via
6 | 1.00mm (39.37mils) | PTH | Slot | L1 (Sig, PWR) - L2 (Sig, GND) | Pad
4 | 1.10mm (43.31mils) | PTH | Round | L1 (Sig, PWR) - L2 (Sig, GND) | Pad
4 | 2.70mm (106.30mils) | PTH | Round | L1 (Sig, PWR) - L2 (Sig, GND) | Pad
Total 67

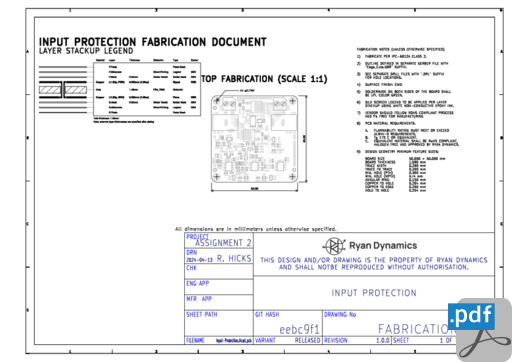
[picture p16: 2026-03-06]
HTML/images/cat_pdf_fabrication_Input-Protection-fabrication.png

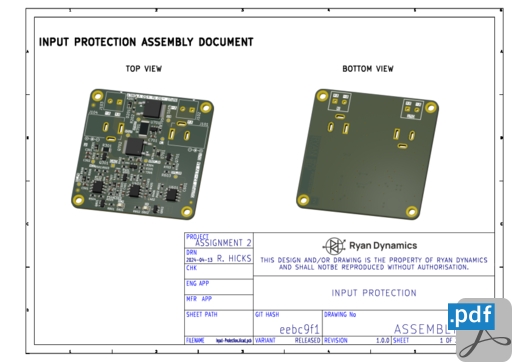
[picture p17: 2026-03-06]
HTML/images/cat_pdf_assembly_Input-Protection-assembly.png

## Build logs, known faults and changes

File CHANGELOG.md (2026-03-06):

# Changelog

## [Unreleased]

## [1.0.0] - 2026-03-06

### Fixed

-   N/A

### Added

-   Schematic and PCB files

### Changed

-   N/A

### Removed

-   N/A

[Unreleased]: https://github.com/Reemuson/MENG4210-Assignment-2/compare/1.0.0...HEAD

[1.0.0]: https://github.com/Reemuson/MENG4210-Assignment-2/compare/1c5c101ffabb5330346188c048466ca0c8d8fb39...1.0.0

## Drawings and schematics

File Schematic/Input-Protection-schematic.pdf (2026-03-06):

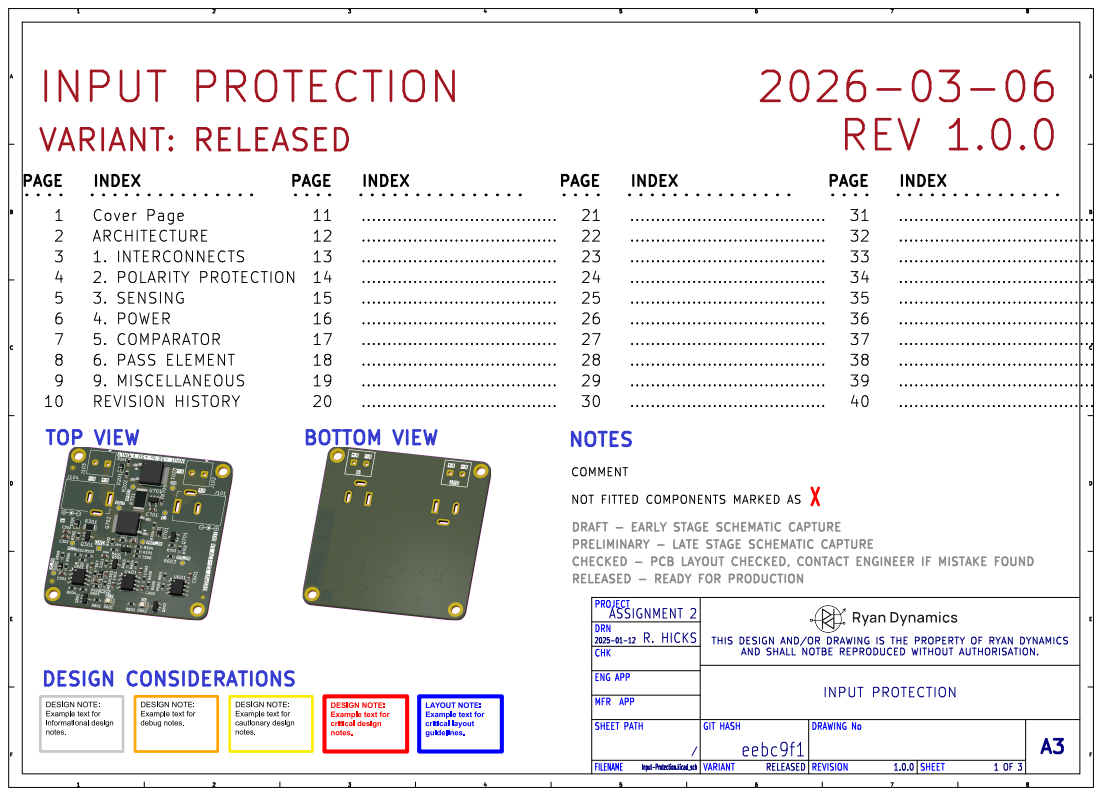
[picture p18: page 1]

NOT FITTED COMPONENTS MARKED AS

DRAFT - EARLY STAGE SCHEMATIC CAPTURE
CHECKED - PCB LAYOUT CHECKED, CONTACT ENGINEER IF MISTAKE FOUND

THIS DESIGN AND/OR DRAWING IS THE PROPERTY OF RYAN DYNAMICS

AND SHALL NOTBE REPRODUCED WITHOUT AUTHORISATION.

File: Schematic.kicad_sch DESIGN NOTE:
Example text for
debug notes.

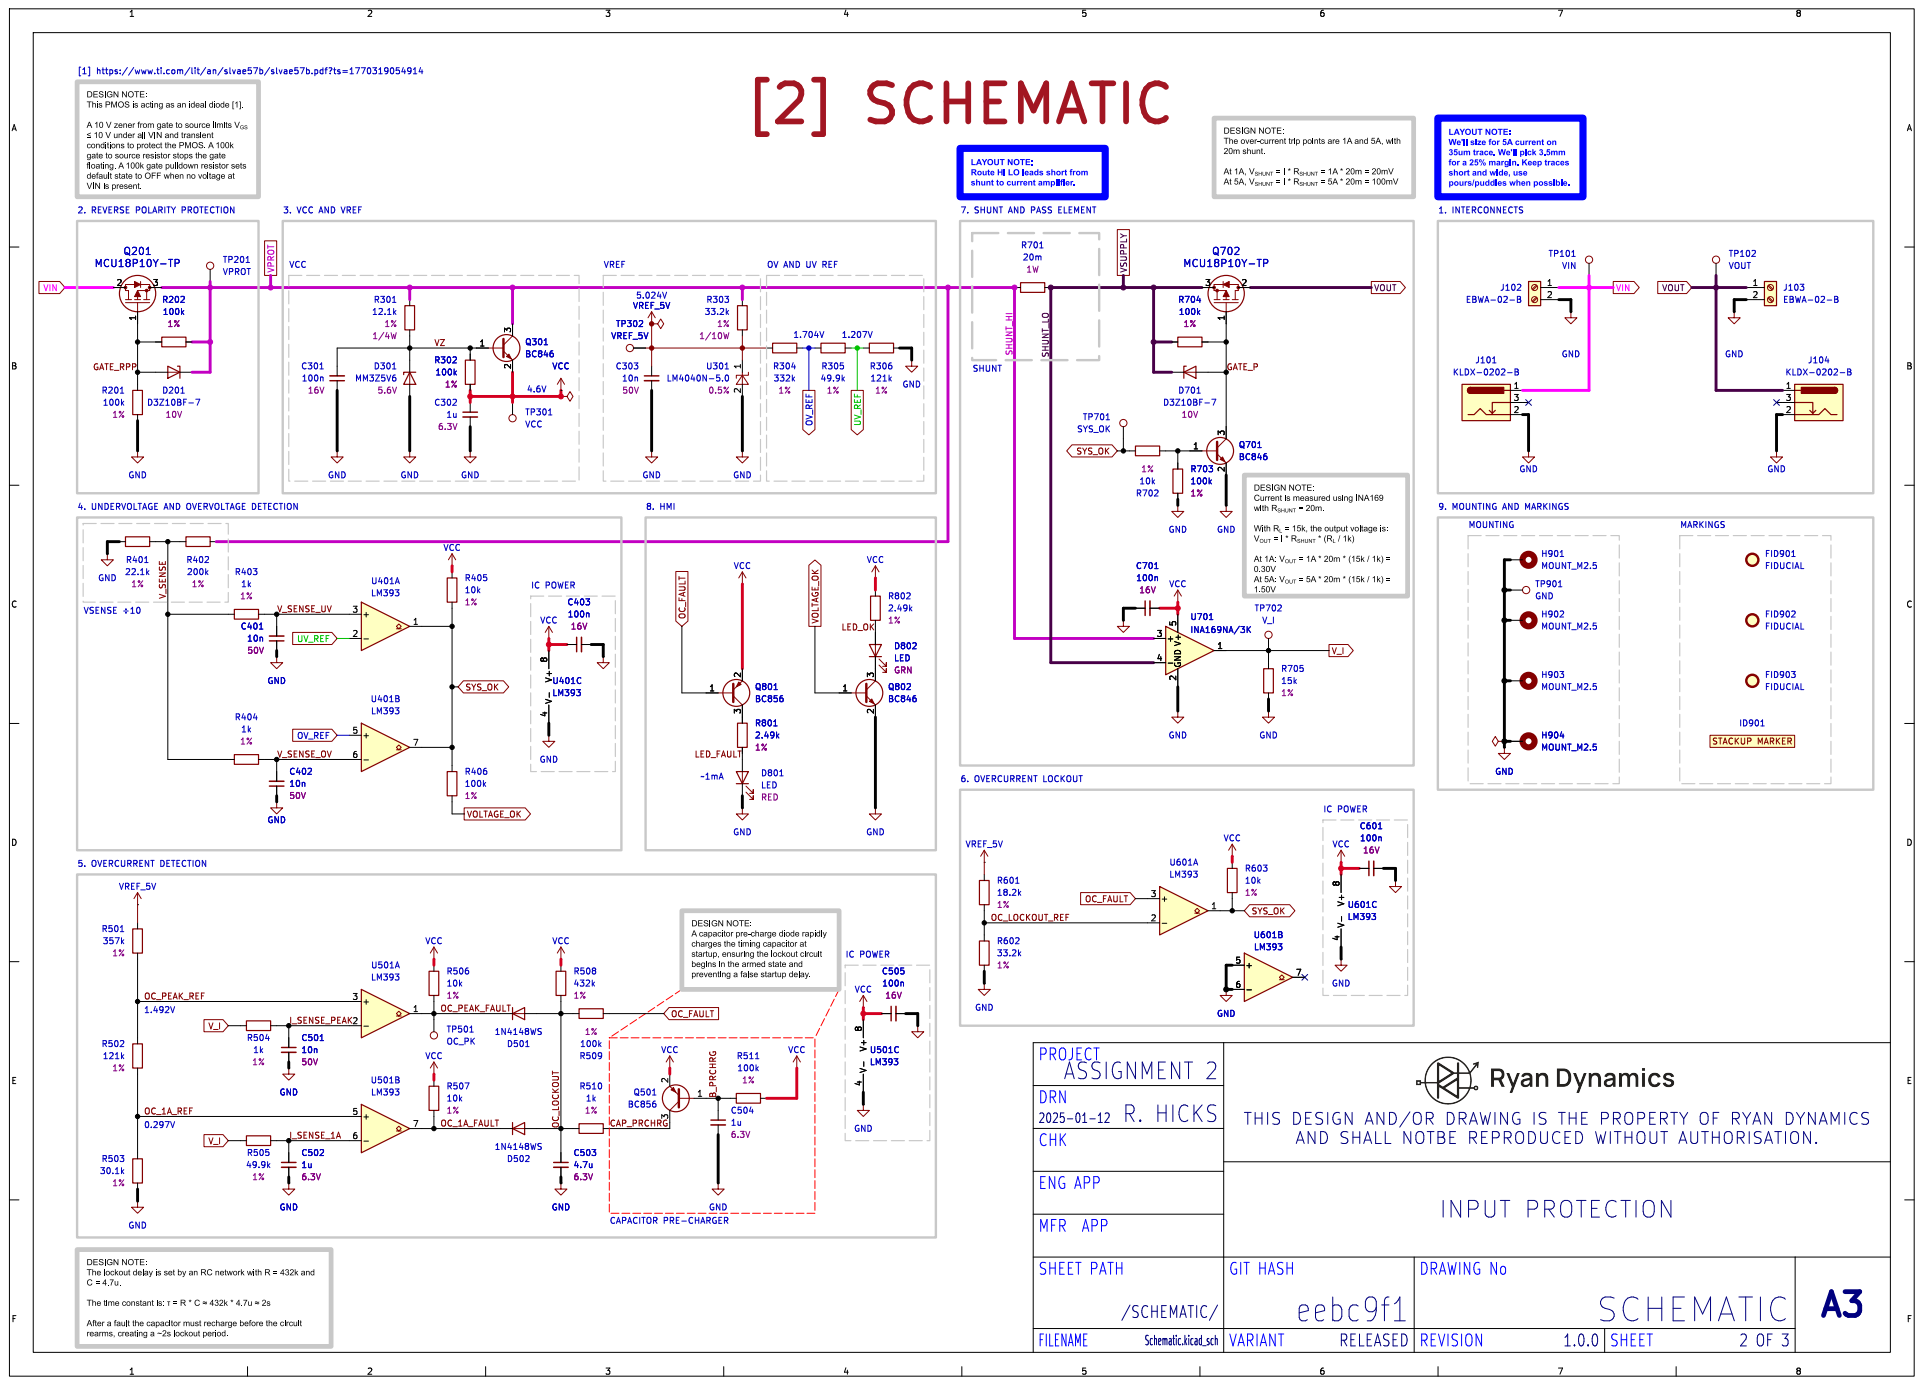
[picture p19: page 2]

[1] https://www.ti.com/lit/an/slvae57b/slvae57b.pdf?ts=1770319054914

DESIGN NOTE: This PMOS is acting as an ideal diode [1]. A 10 V zener from gate to source limits V_{GS}

þÿ"d10 V under all VIN and transient conditions to protect the PMOS. A 100k gate to source resistor stops the gate

LAYOUT NOTE: We'll size for 5A current on
At 5A, V_{SHUNT} = I * R_{SHUNT} = 5A * 20m = 100mV DESIGN NOTE: Current is measured using INA169 with R_{SHUNT} = 20m. With R_{L} = 15k, the output voltage is: V_{OUT} = I * R_{SHUNT} * (R_{L} / 1k) At 1A: V_{OUT} = 1A * 20m * (15k / 1k) =

20m shunt. At 1A, V_{SHUNT} = I * R_{SHUNT} = 1A * 20m = 20mV

35um trace. We'll pick 3.5mm
for a 25% margin. Keep traces

LAYOUT NOTE: Route HI LO leads short from

4. UNDERVOLTAGE AND OVERVOLTAGE DETECTION

OC_LOCKOUT_REF B_PRCHRG
DESIGN NOTE: A capacitor pre-charge diode rapidly

charges the timing capacitor at startup, ensuring the lockout circuit begins in the armed state and

preventing a false startup delay. DESIGN NOTE: The lockout delay is set by an RC network with R = 432k and C = 4.7u. The time constant is: þÿÄ= R * C þÿ"H432k * 4.7u þÿ"H2s After a fault the capacitor must recharge before the circuit rearms, creating a ~2s lockout period.

THIS DESIGN AND/OR DRAWING IS THE PROPERTY OF RYAN DYNAMICS

AND SHALL NOTBE REPRODUCED WITHOUT AUTHORISATION.

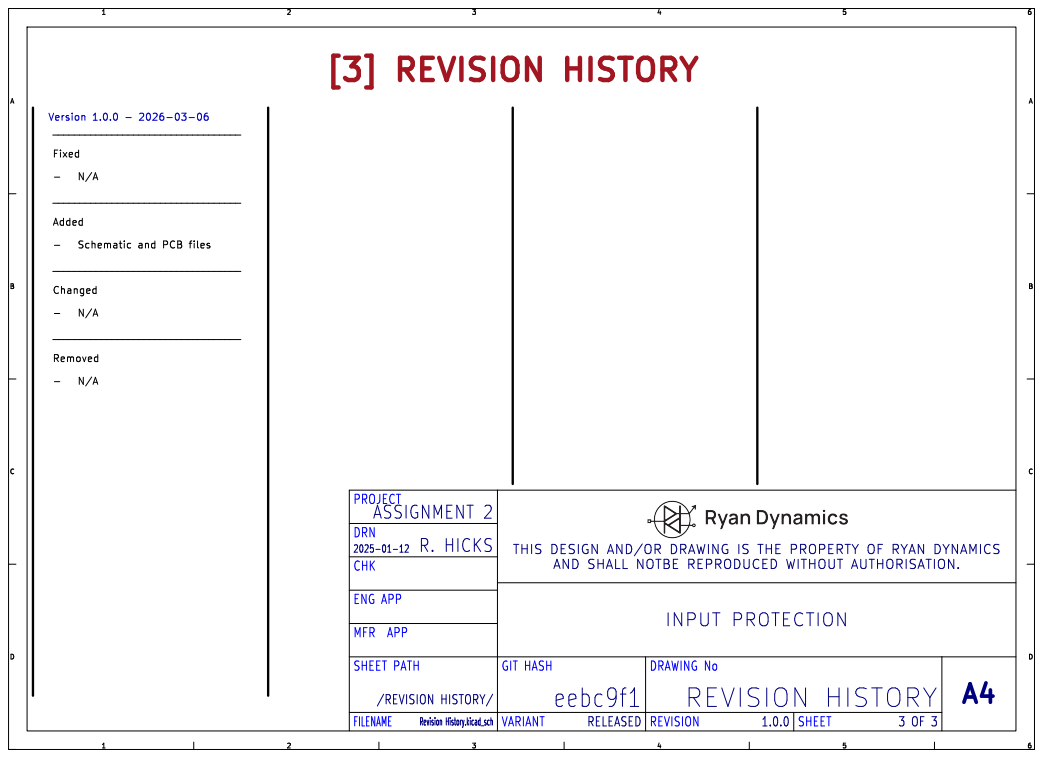
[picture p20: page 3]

THIS DESIGN AND/OR DRAWING IS THE PROPERTY OF RYAN DYNAMICS

AND SHALL NOTBE REPRODUCED WITHOUT AUTHORISATION.

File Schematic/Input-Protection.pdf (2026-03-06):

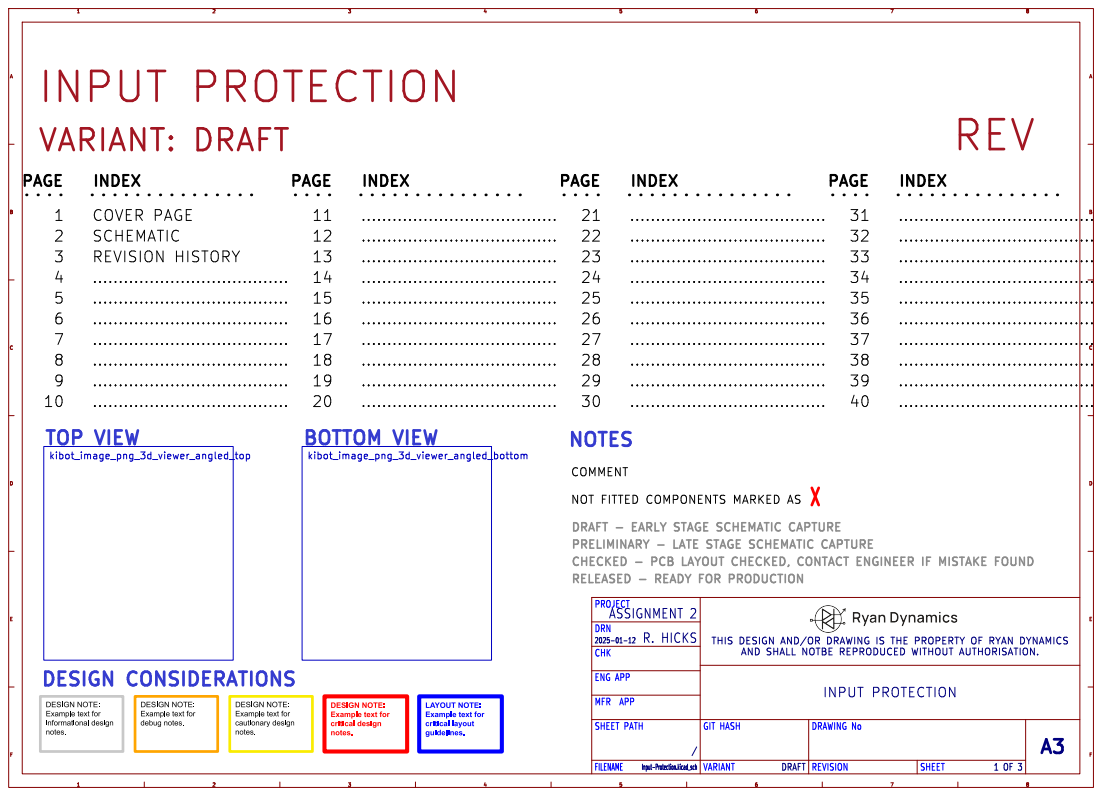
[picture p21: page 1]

NOT FITTED COMPONENTS MARKED AS

PRELIMINARY - LATE STAGE SCHEMATIC CAPTURE
CHECKED - PCB LAYOUT CHECKED, CONTACT ENGINEER IF MISTAKE FOUND

THIS DESIGN AND/OR DRAWING IS THE PROPERTY OF RYAN DYNAMICS

AND SHALL NOTBE REPRODUCED WITHOUT AUTHORISATION.

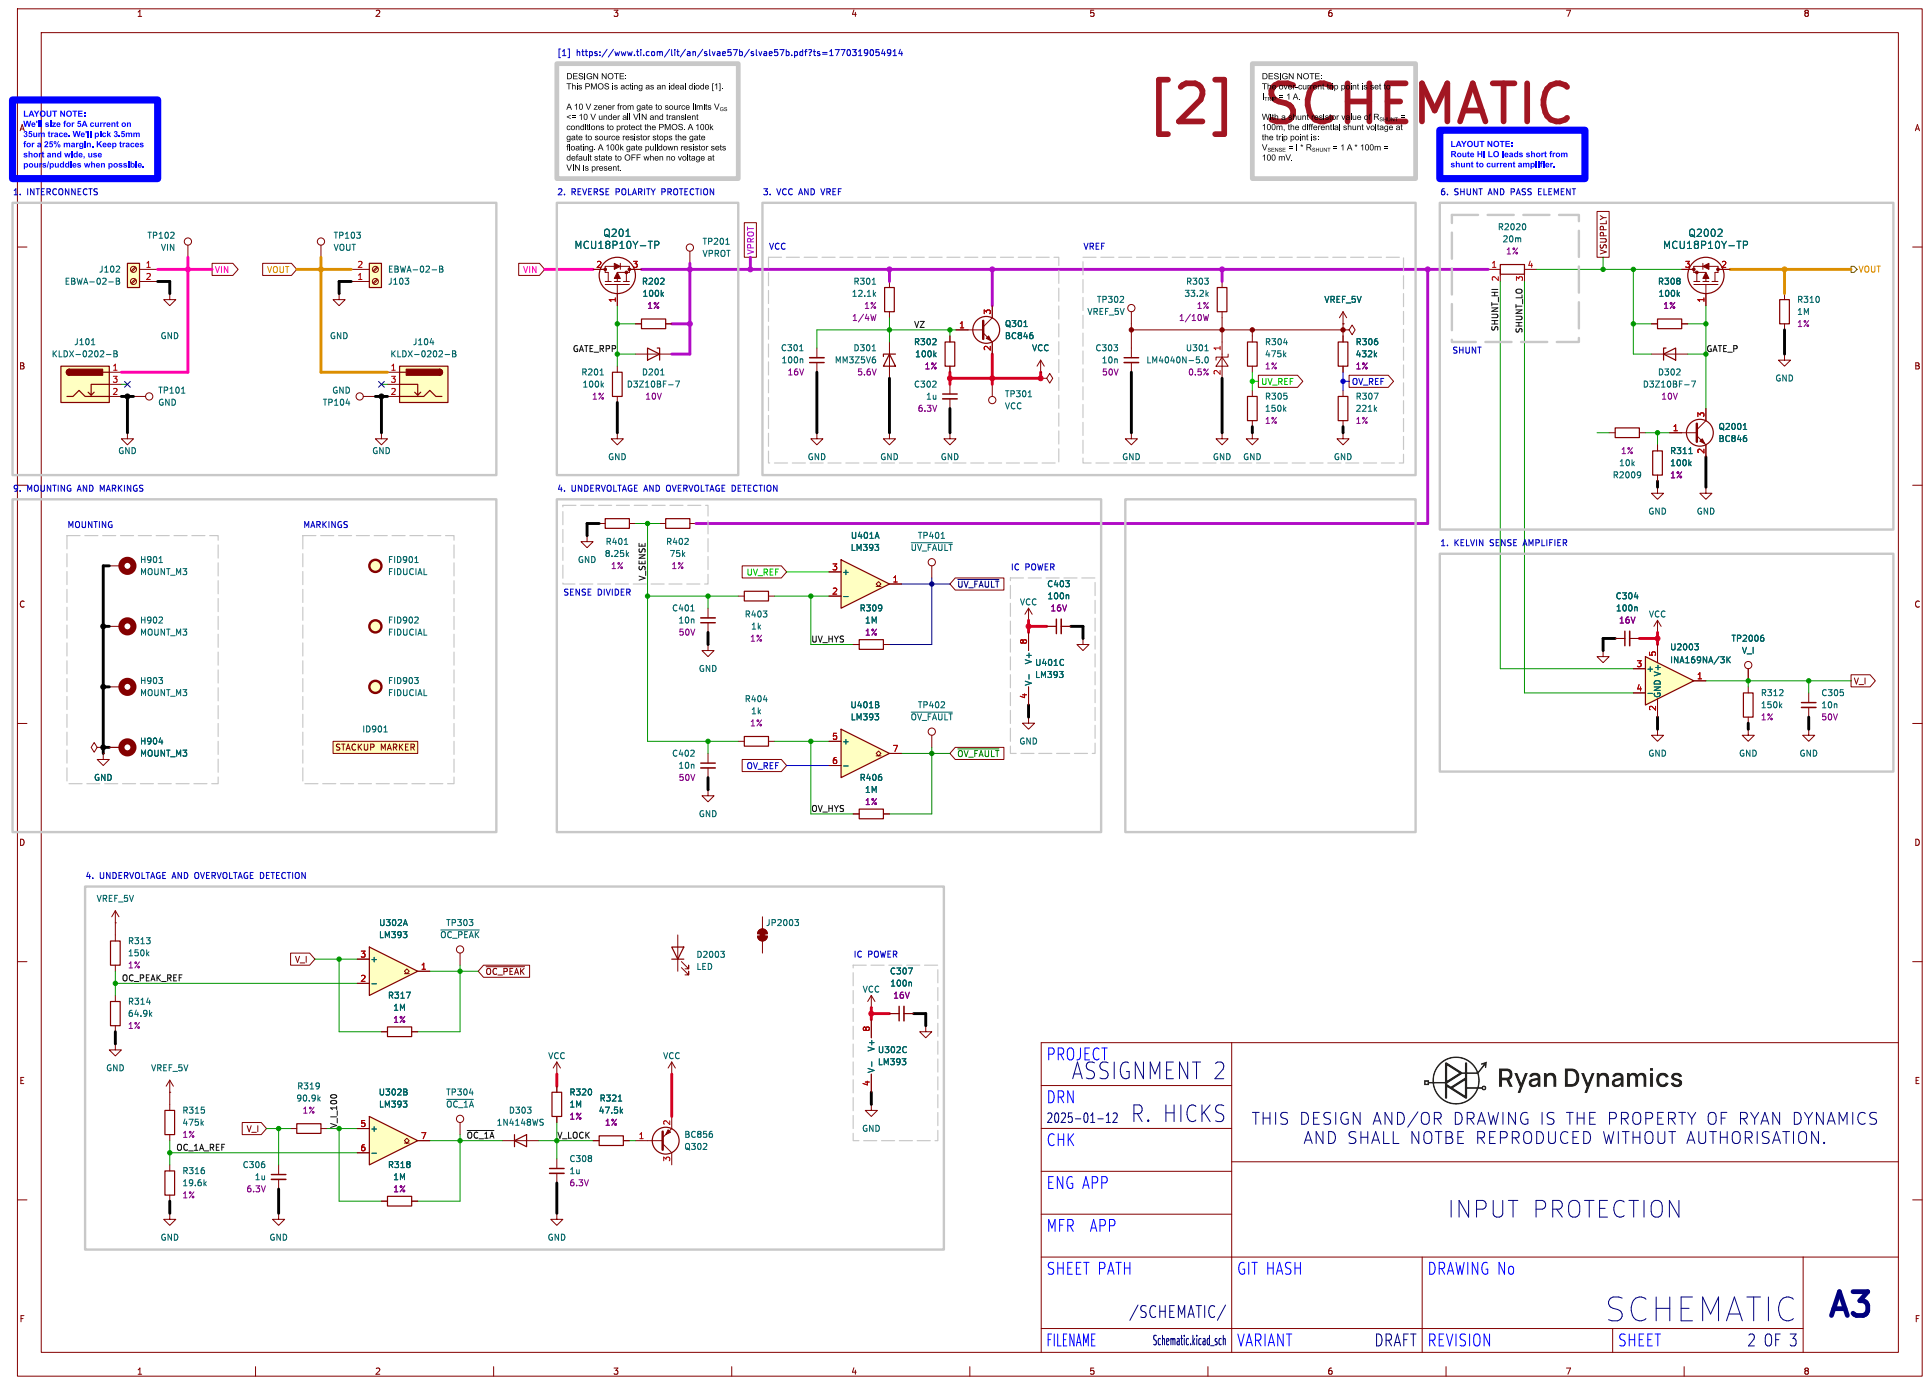
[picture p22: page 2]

[1] https://www.ti.com/lit/an/slvae57b/slvae57b.pdf?ts=1770319054914

robustness. DESIGN NOTE: This PMOS is acting as an ideal diode [1]. A 10 V zener from gate to source limits V_{GS} <= 10 V under all VIN and transient conditions to protect the PMOS. A 100k gate to source resistor stops the gate

shunt to current amplifier. DESIGN NOTE: The over-current trip point is set to
[2] SCHEMATIC

I_{TRIP} = 1 A. With a shunt resistor value of R_{SHUNT} =

LAYOUT NOTE: We'll size for 5A current on
35um trace. We'll pick 3.5mm
for a 25% margin. Keep traces

100m, the differential shunt voltage at
the trip point is: V_{SENSE} = I * R_{SHUNT} = 1 A * 100m =

2. REVERSE POLARITY PROTECTION MOUNTING
TP102 VIN GND

6. SHUNT AND PASS ELEMENT

4. UNDERVOLTAGE AND OVERVOLTAGE DETECTION

[3] https://www.ti.com/lit/an/snoaa35f/snoaa35f.pdf?ts=1770697404856 MARKINGS

THIS DESIGN AND/OR DRAWING IS THE PROPERTY OF RYAN DYNAMICS

AND SHALL NOTBE REPRODUCED WITHOUT AUTHORISATION.

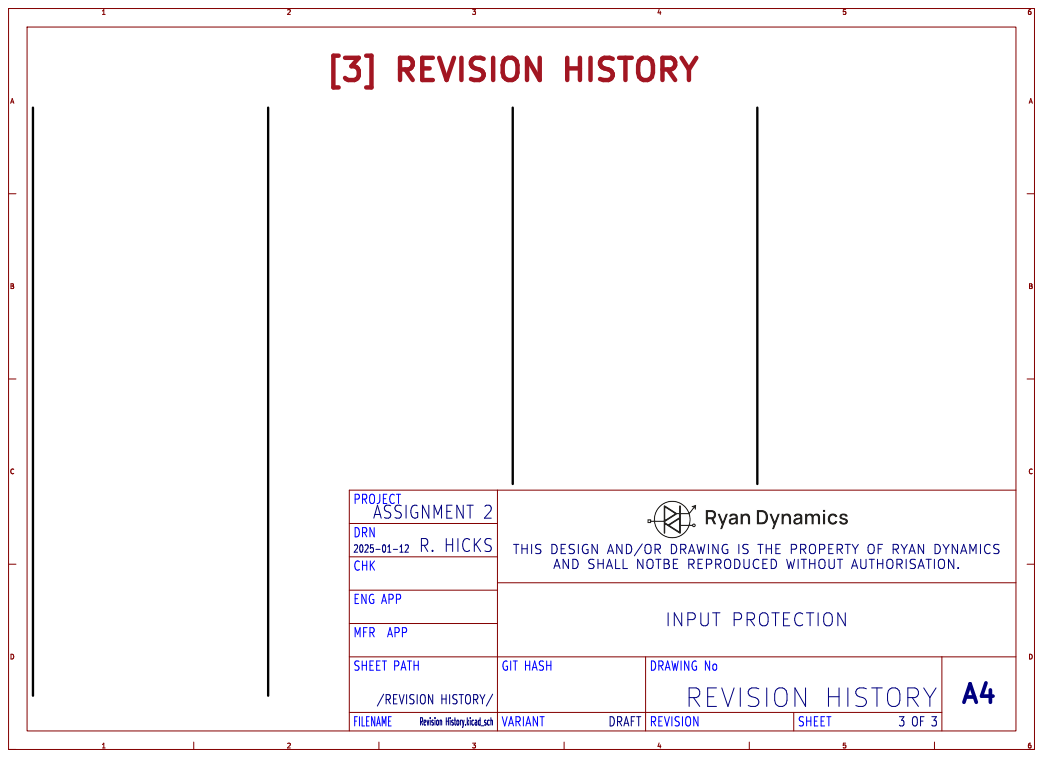
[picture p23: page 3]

THIS DESIGN AND/OR DRAWING IS THE PROPERTY OF RYAN DYNAMICS

AND SHALL NOTBE REPRODUCED WITHOUT AUTHORISATION.

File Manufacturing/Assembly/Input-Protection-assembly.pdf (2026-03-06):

INPUT | PROTECTION | ASSEMBLY | DOCUMENT
TOP VIEW | BOTTOM | VIEW

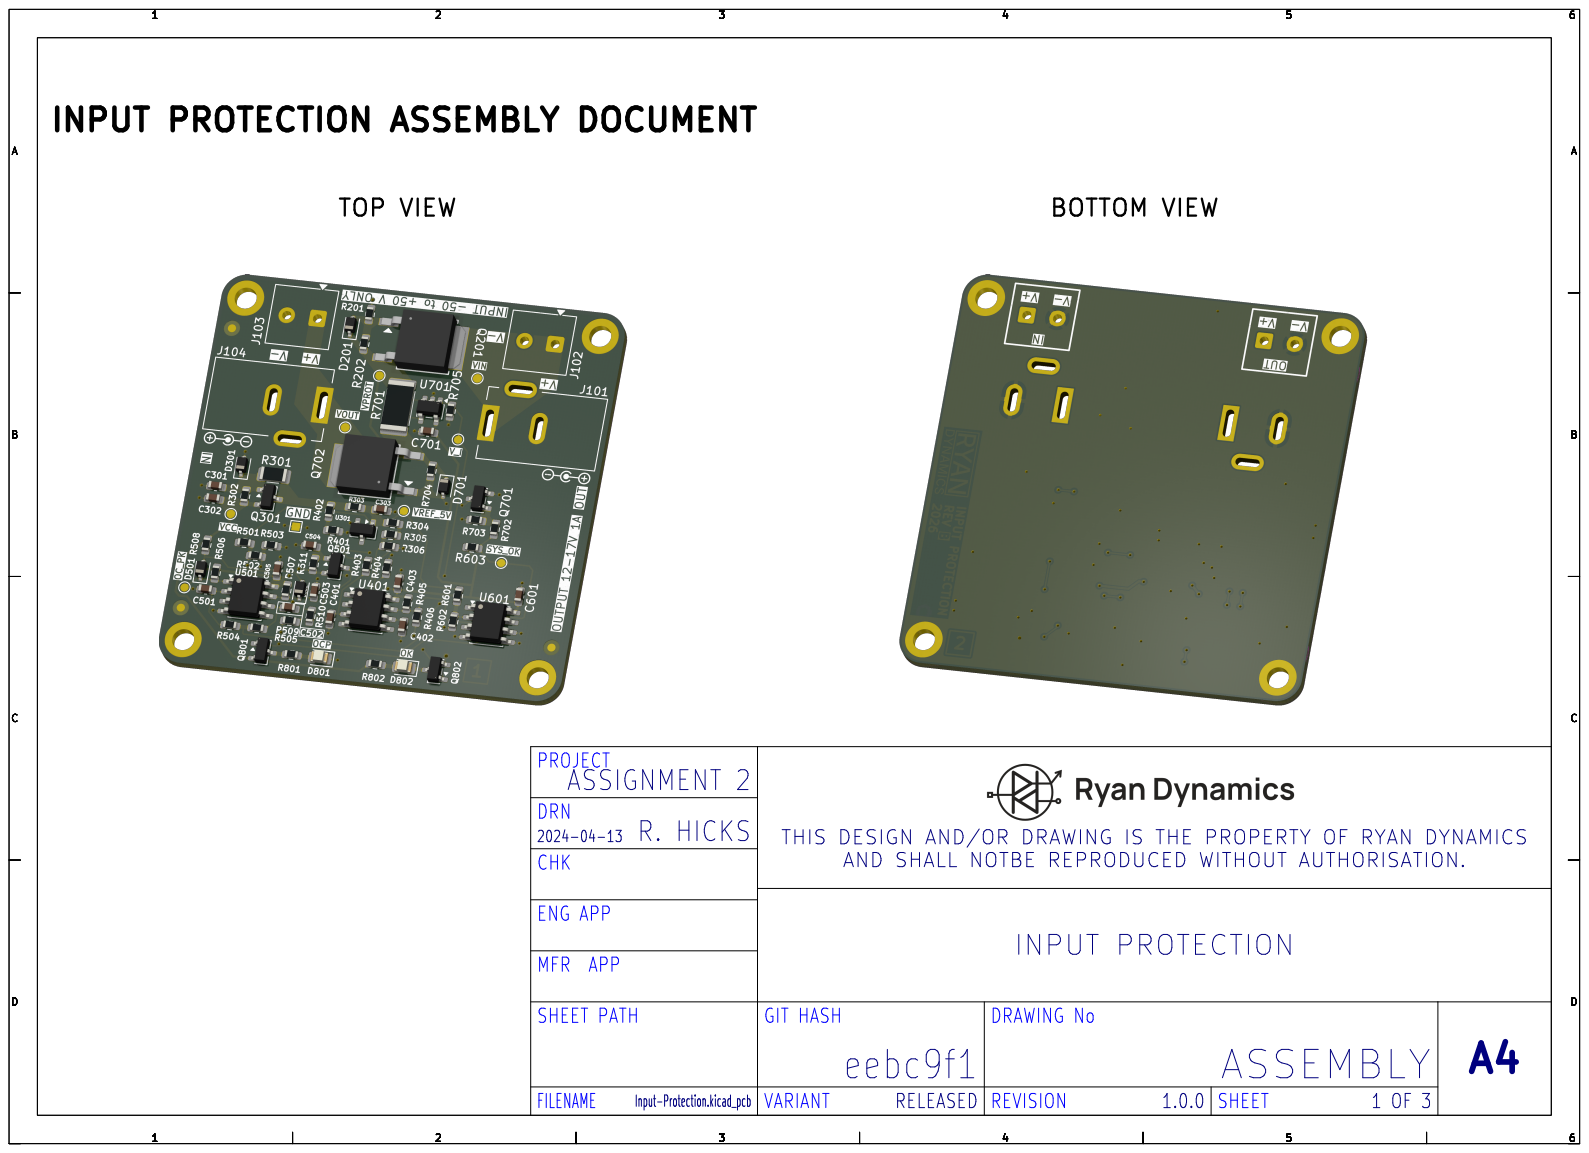
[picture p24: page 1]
DRAWING No; ASSIGNMENT 2; SHEET; ASSEMBLY; PROJECT; Input-Protection.kicad_pcb; INPUT; PROTECTION; FILENAME; ENG APP; RELEASED; 2024-04-13 CHK; GIT; HASH; VARIANT; PATH; MFR; APP; DRN; REVISION; R. HICKS; eebc9f1; THIS DESIGN AND/OR; DRAWING IS THE PROPERTY OF RYAN DYNAMICSAND SHALL NOTBE REPRODUCED WITHOUT AUTHORISATION.

# TOP ASSEMBLY (SCALE 1:1)

# INPUT PROTECTION ASSEMBLY DOCUMENT

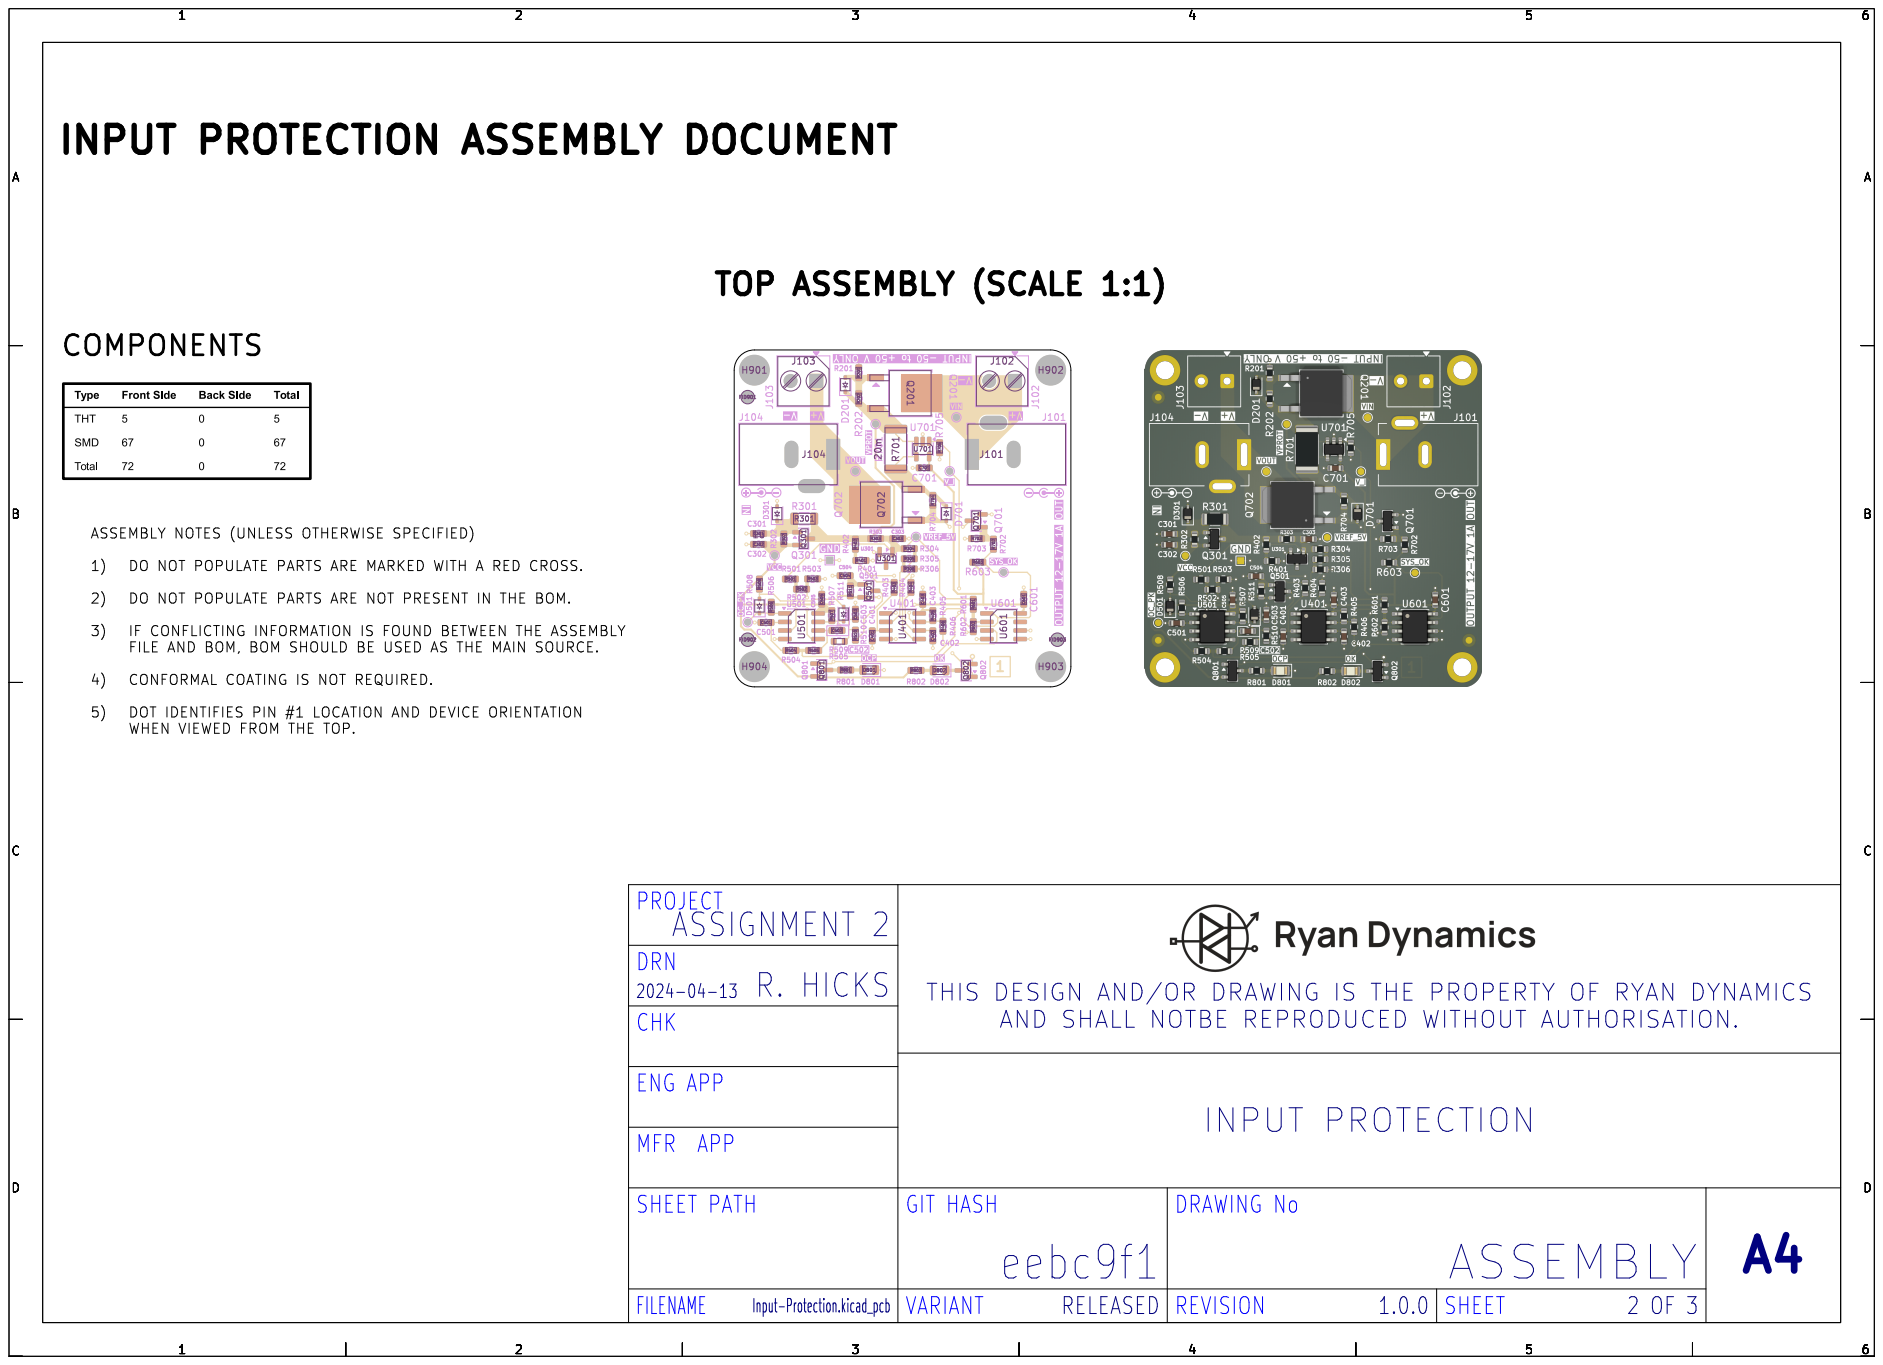
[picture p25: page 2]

1) DO NOT POPULATE PARTS ARE MARKED WITH A RED CROSS.

2) DO NOT POPULATE PARTS ARE NOT PRESENT IN THE BOM.

3) IF CONFLICTING INFORMATION IS FOUND BETWEEN THE ASSEMBLY
FILE AND BOM, BOM SHOULD BE USED AS THE MAIN SOURCE.

4) CONFORMAL COATING IS NOT REQUIRED.

5) DOT IDENTIFIES PIN #1 LOCATION AND DEVICE ORIENTATION
WHEN VIEWED FROM THE TOP.

PROJECT
ASSIGNMENT 2
DRN
THIS DESIGN AND/OR DRAWING IS THE PROPERTY OF RYAN DYNAMICSAND SHALL NOTBE REPRODUCED WITHOUT AUTHORISATION.
CHK

BOTTOM ASSEMBLY | (SCALE | 1:1)
INPUT | PROTECTION | ASSEMBLY | DOCUMENT

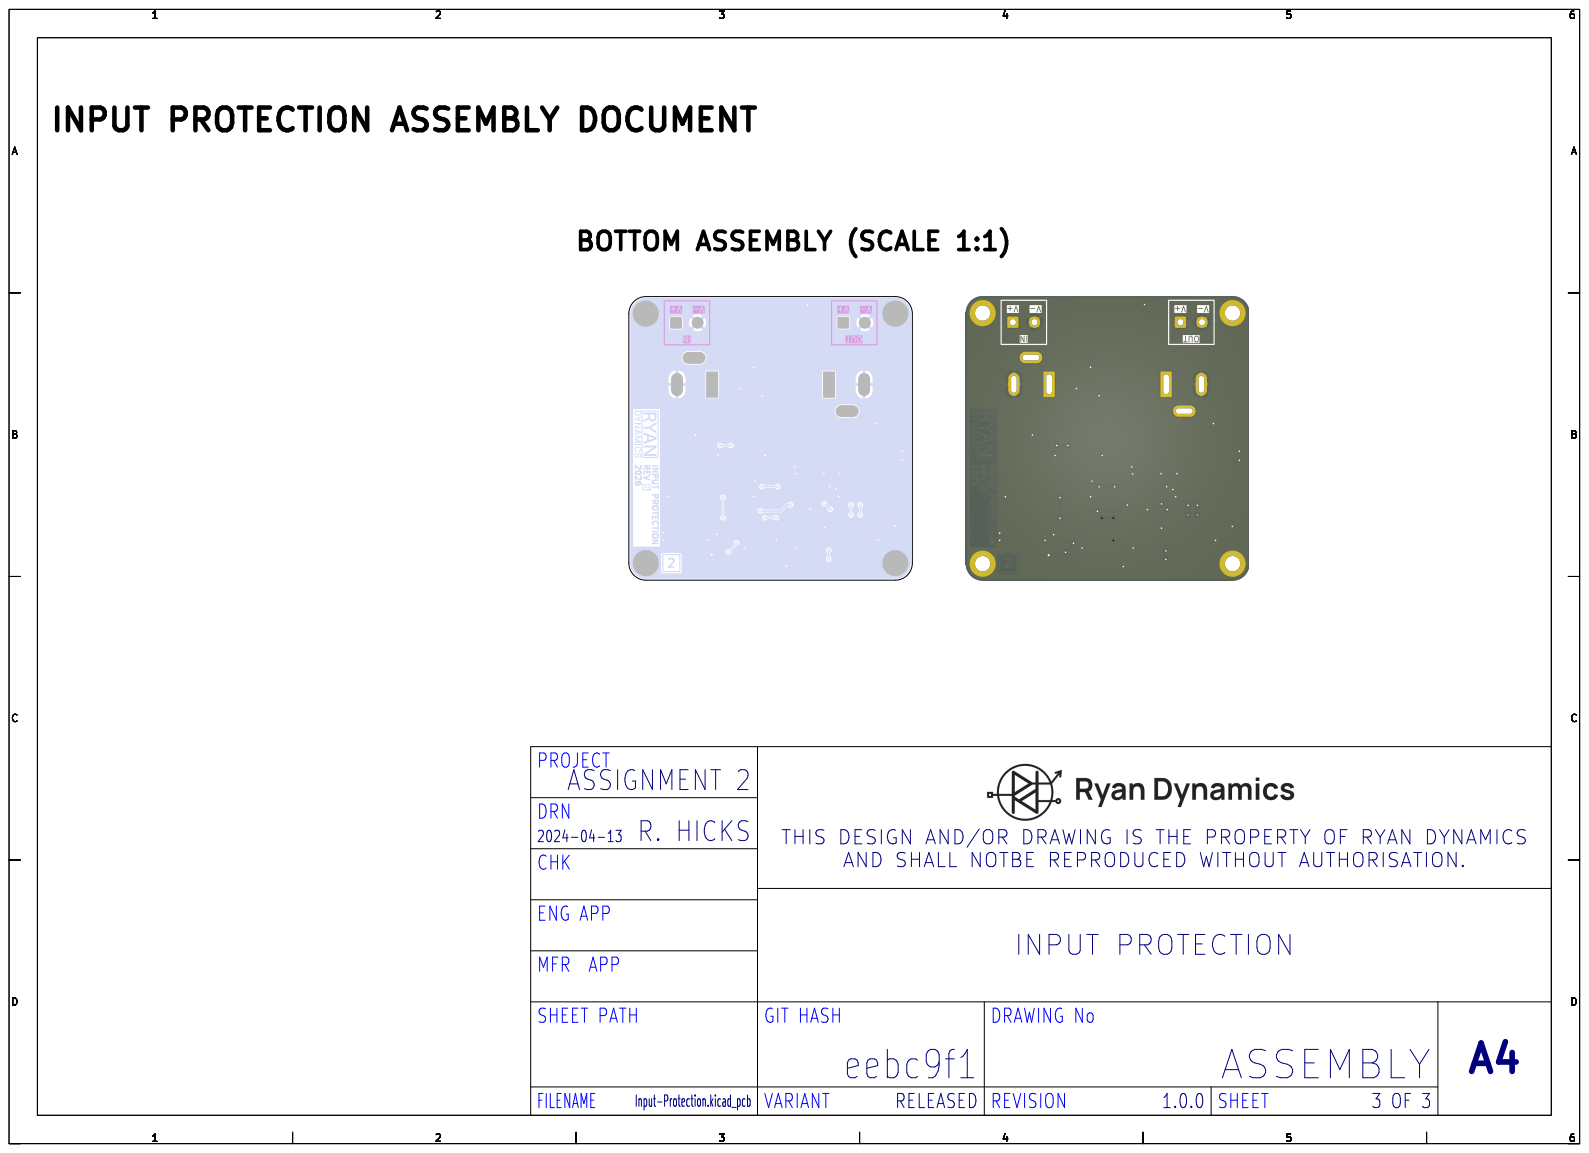
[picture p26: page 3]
DRAWING No; ASSIGNMENT 2; ASSEMBLY; PROJECT; INPUT; PROTECTION; ENG APP; 2024-04-13 CHK; GIT; HASH; SHEET; PATH; MFR; APP; DRN; R. HICKS; eebc9f1; THIS DESIGN AND/OR; DRAWING IS THE PROPERTY OF RYAN DYNAMICSAND SHALL NOTBE REPRODUCED WITHOUT AUTHORISATION.; REV; INPUT PROTECTION

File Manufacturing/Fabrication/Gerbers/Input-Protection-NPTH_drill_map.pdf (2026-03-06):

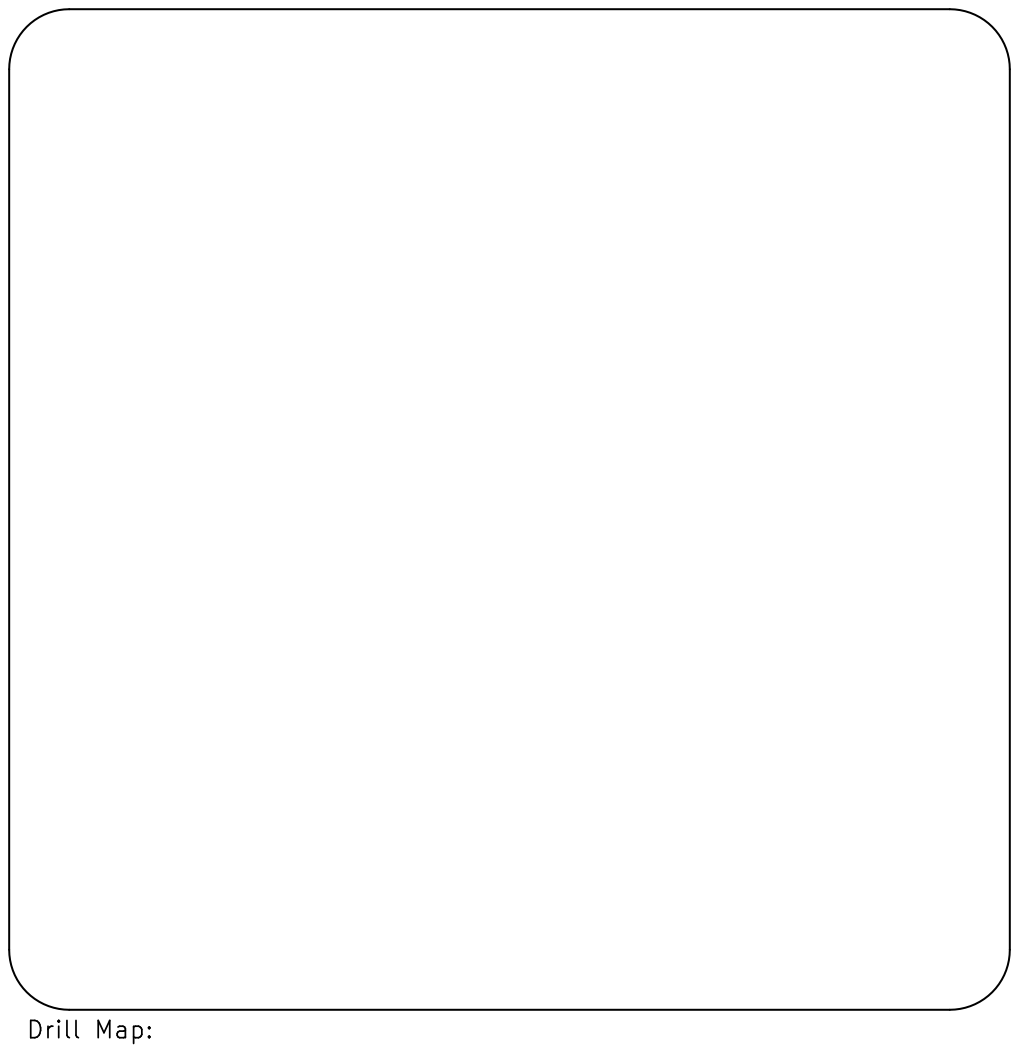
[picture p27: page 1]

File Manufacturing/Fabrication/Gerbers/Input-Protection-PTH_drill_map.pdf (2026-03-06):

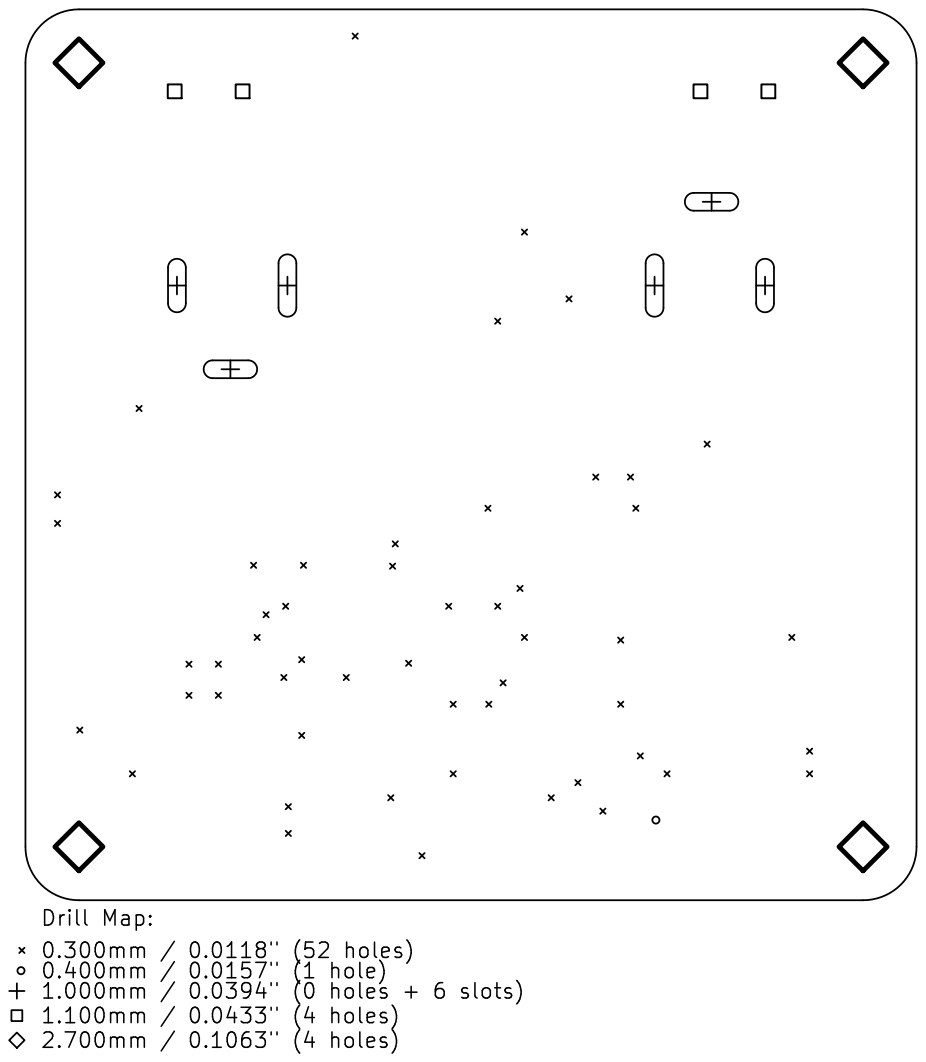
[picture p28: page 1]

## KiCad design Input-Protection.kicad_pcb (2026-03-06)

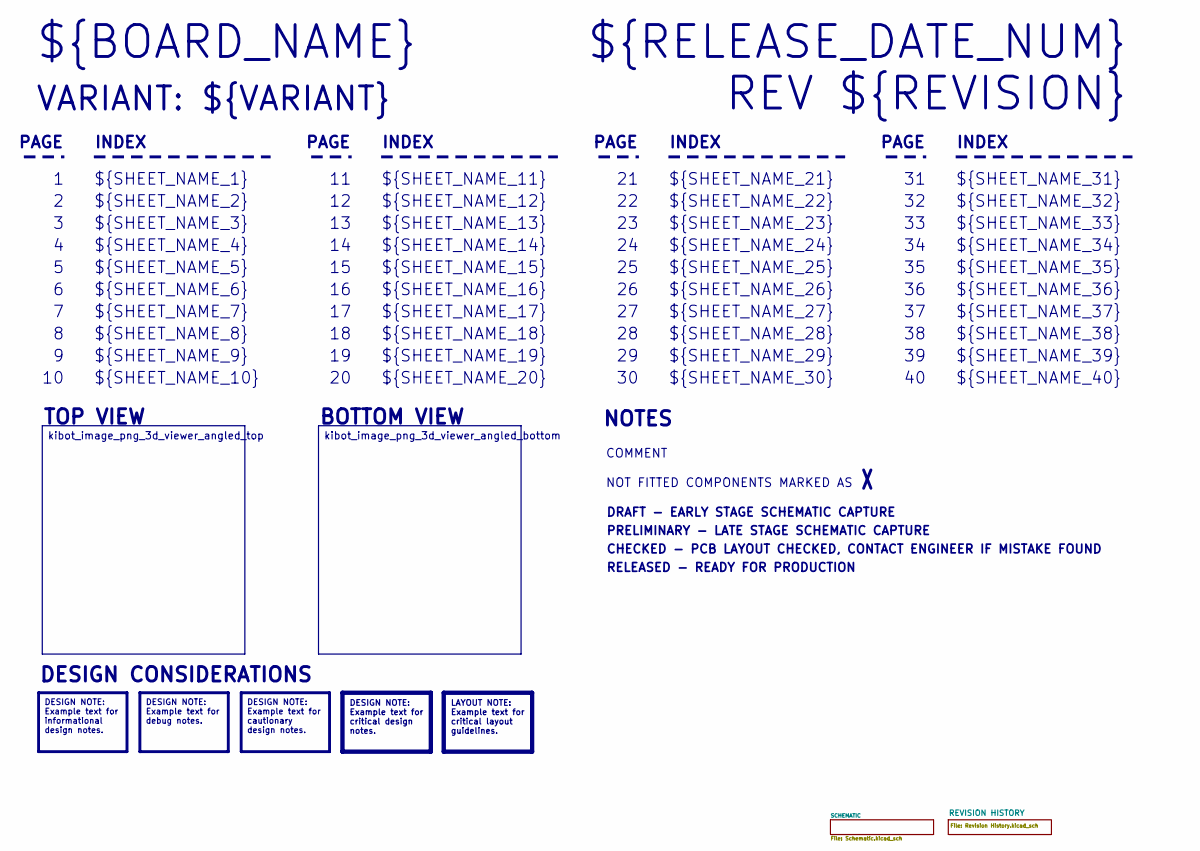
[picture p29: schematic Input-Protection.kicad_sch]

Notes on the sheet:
VARIANT: ${VARIANT}
${SHEET_NAME_24}
INDEX
PAGE
${SHEET_NAME_22}
DRAFT - EARLY STAGE SCHEMATIC CAPTURE
${SHEET_NAME_12}
${SHEET_NAME_8}
${SHEET_NAME_2}
${SHEET_NAME_5}
${SHEET_NAME_20}
${SHEET_NAME_23}
${RELEASE_DATE_NUM}
${SHEET_NAME_35}
${SHEET_NAME_11}
CHECKED - PCB LAYOUT CHECKED, CONTACT ENGINEER IF MISTAKE FOUND
${SHEET_NAME_6}
${SHEET_NAME_37}
NOT FITTED COMPONENTS MARKED AS
${SHEET_NAME_26}
${SHEET_NAME_36}
REV ${REVISION}
${SHEET_NAME_15}
BOTTOM VIEW
${SHEET_NAME_14}
${SHEET_NAME_21}
${SHEET_NAME_17}
${SHEET_NAME_18}
${SHEET_NAME_7}
${SHEET_NAME_31}
${BOARD_NAME}
NOTES
${SHEET_NAME_40}
${SHEET_NAME_39}
${SHEET_NAME_32}
${SHEET_NAME_1}
${SHEET_NAME_9}
${SHEET_NAME_38}
${SHEET_NAME_29}
RELEASED - READY FOR PRODUCTION

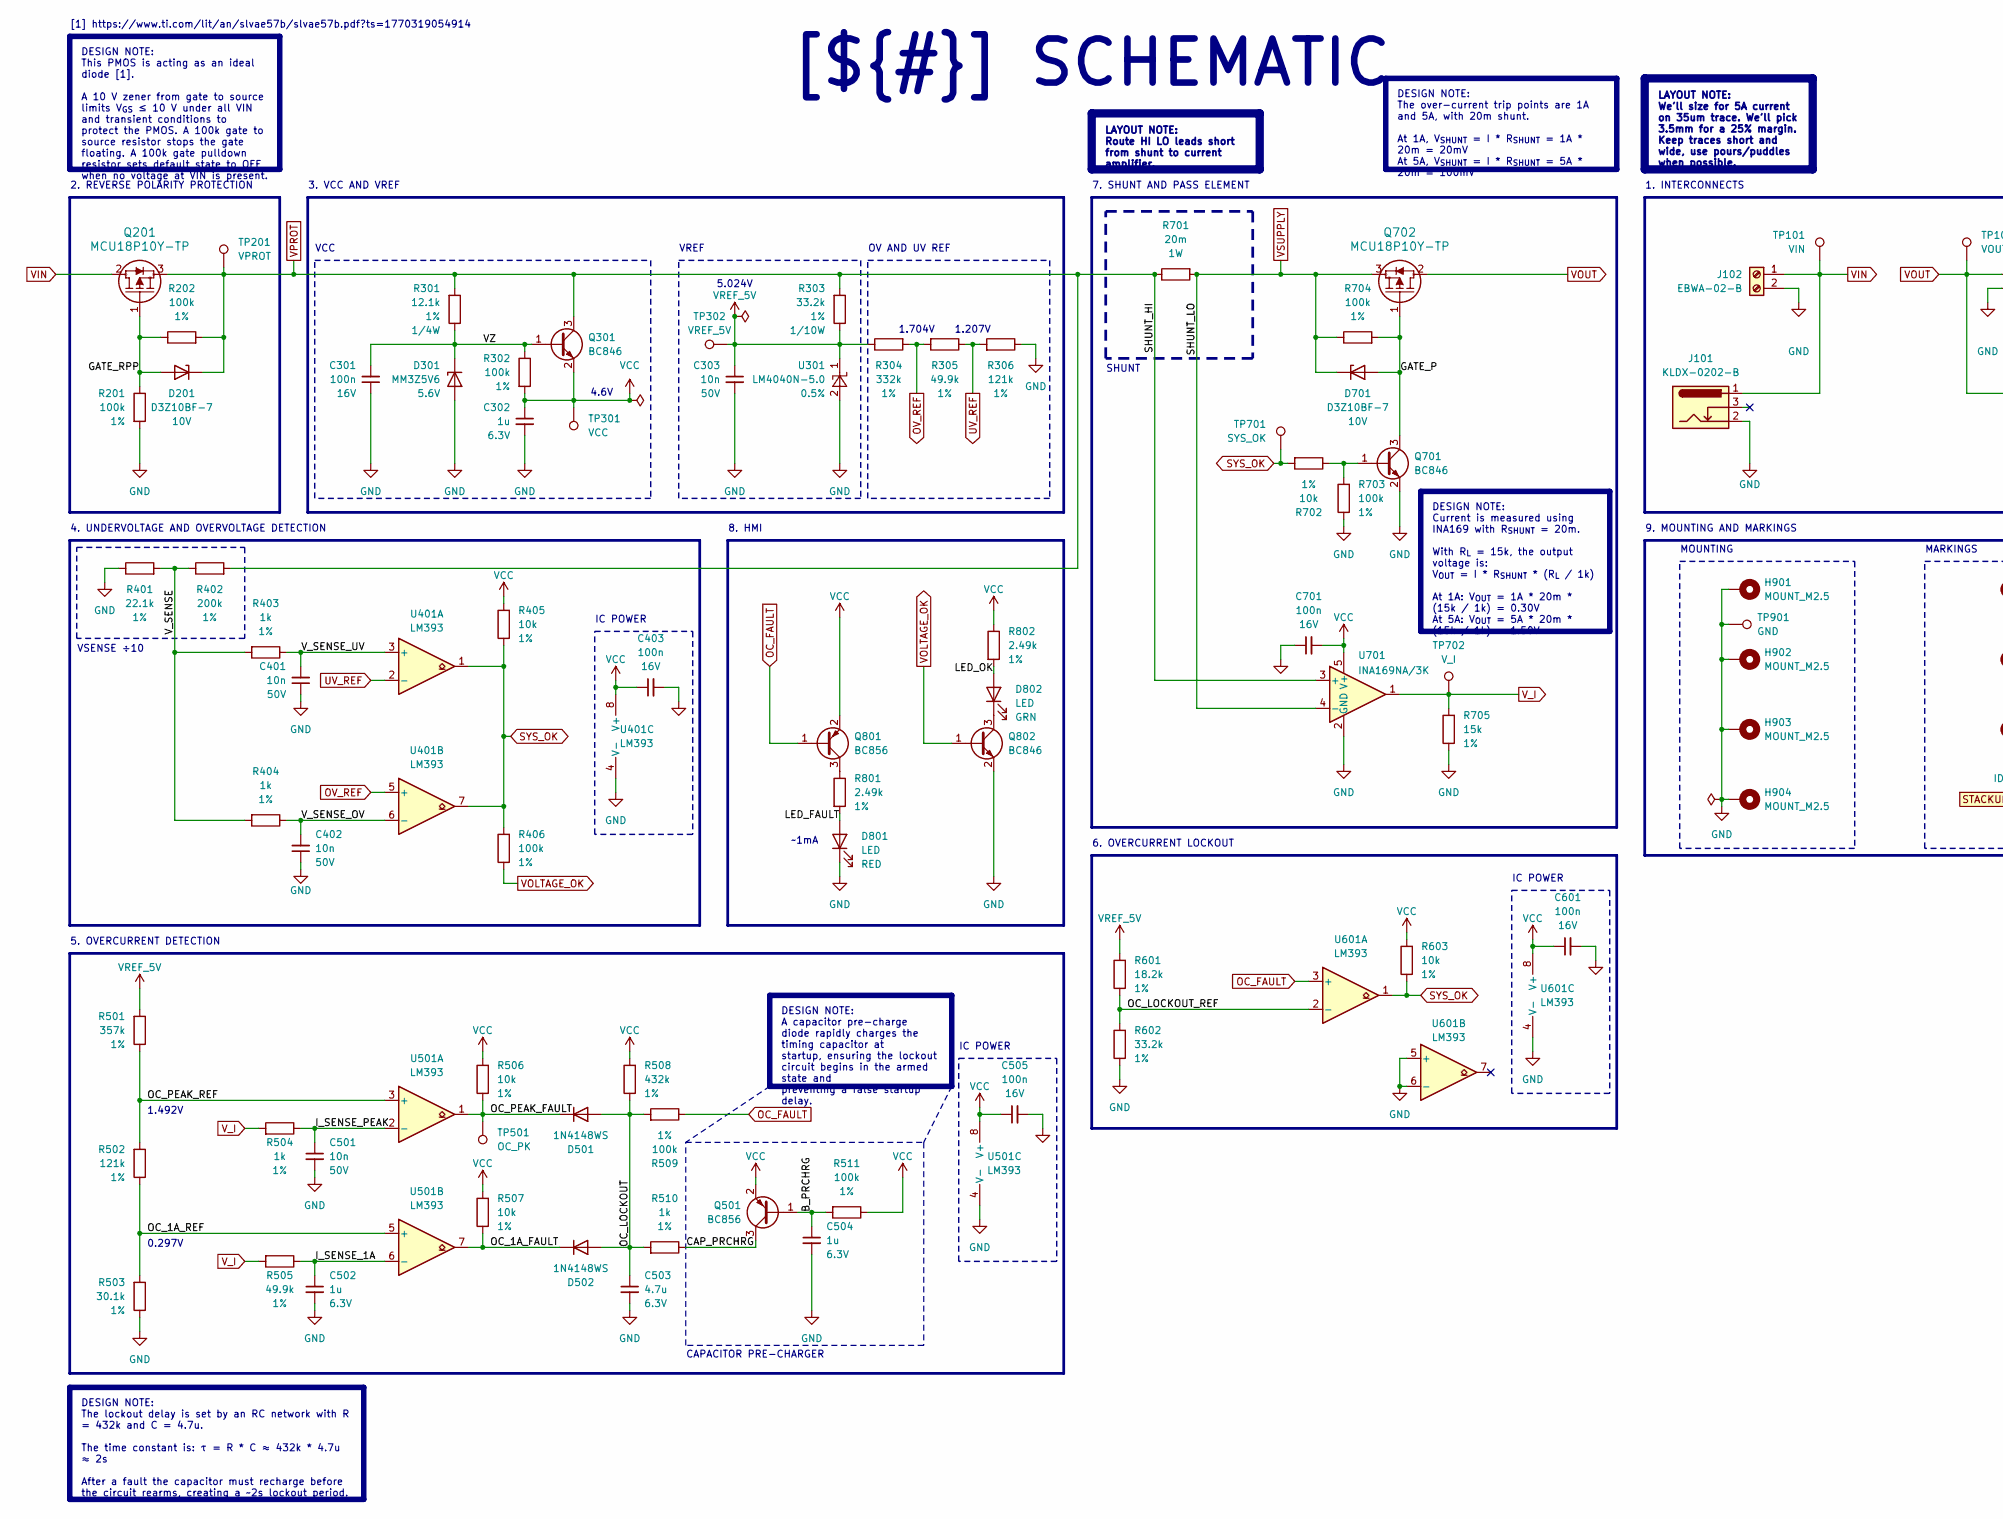
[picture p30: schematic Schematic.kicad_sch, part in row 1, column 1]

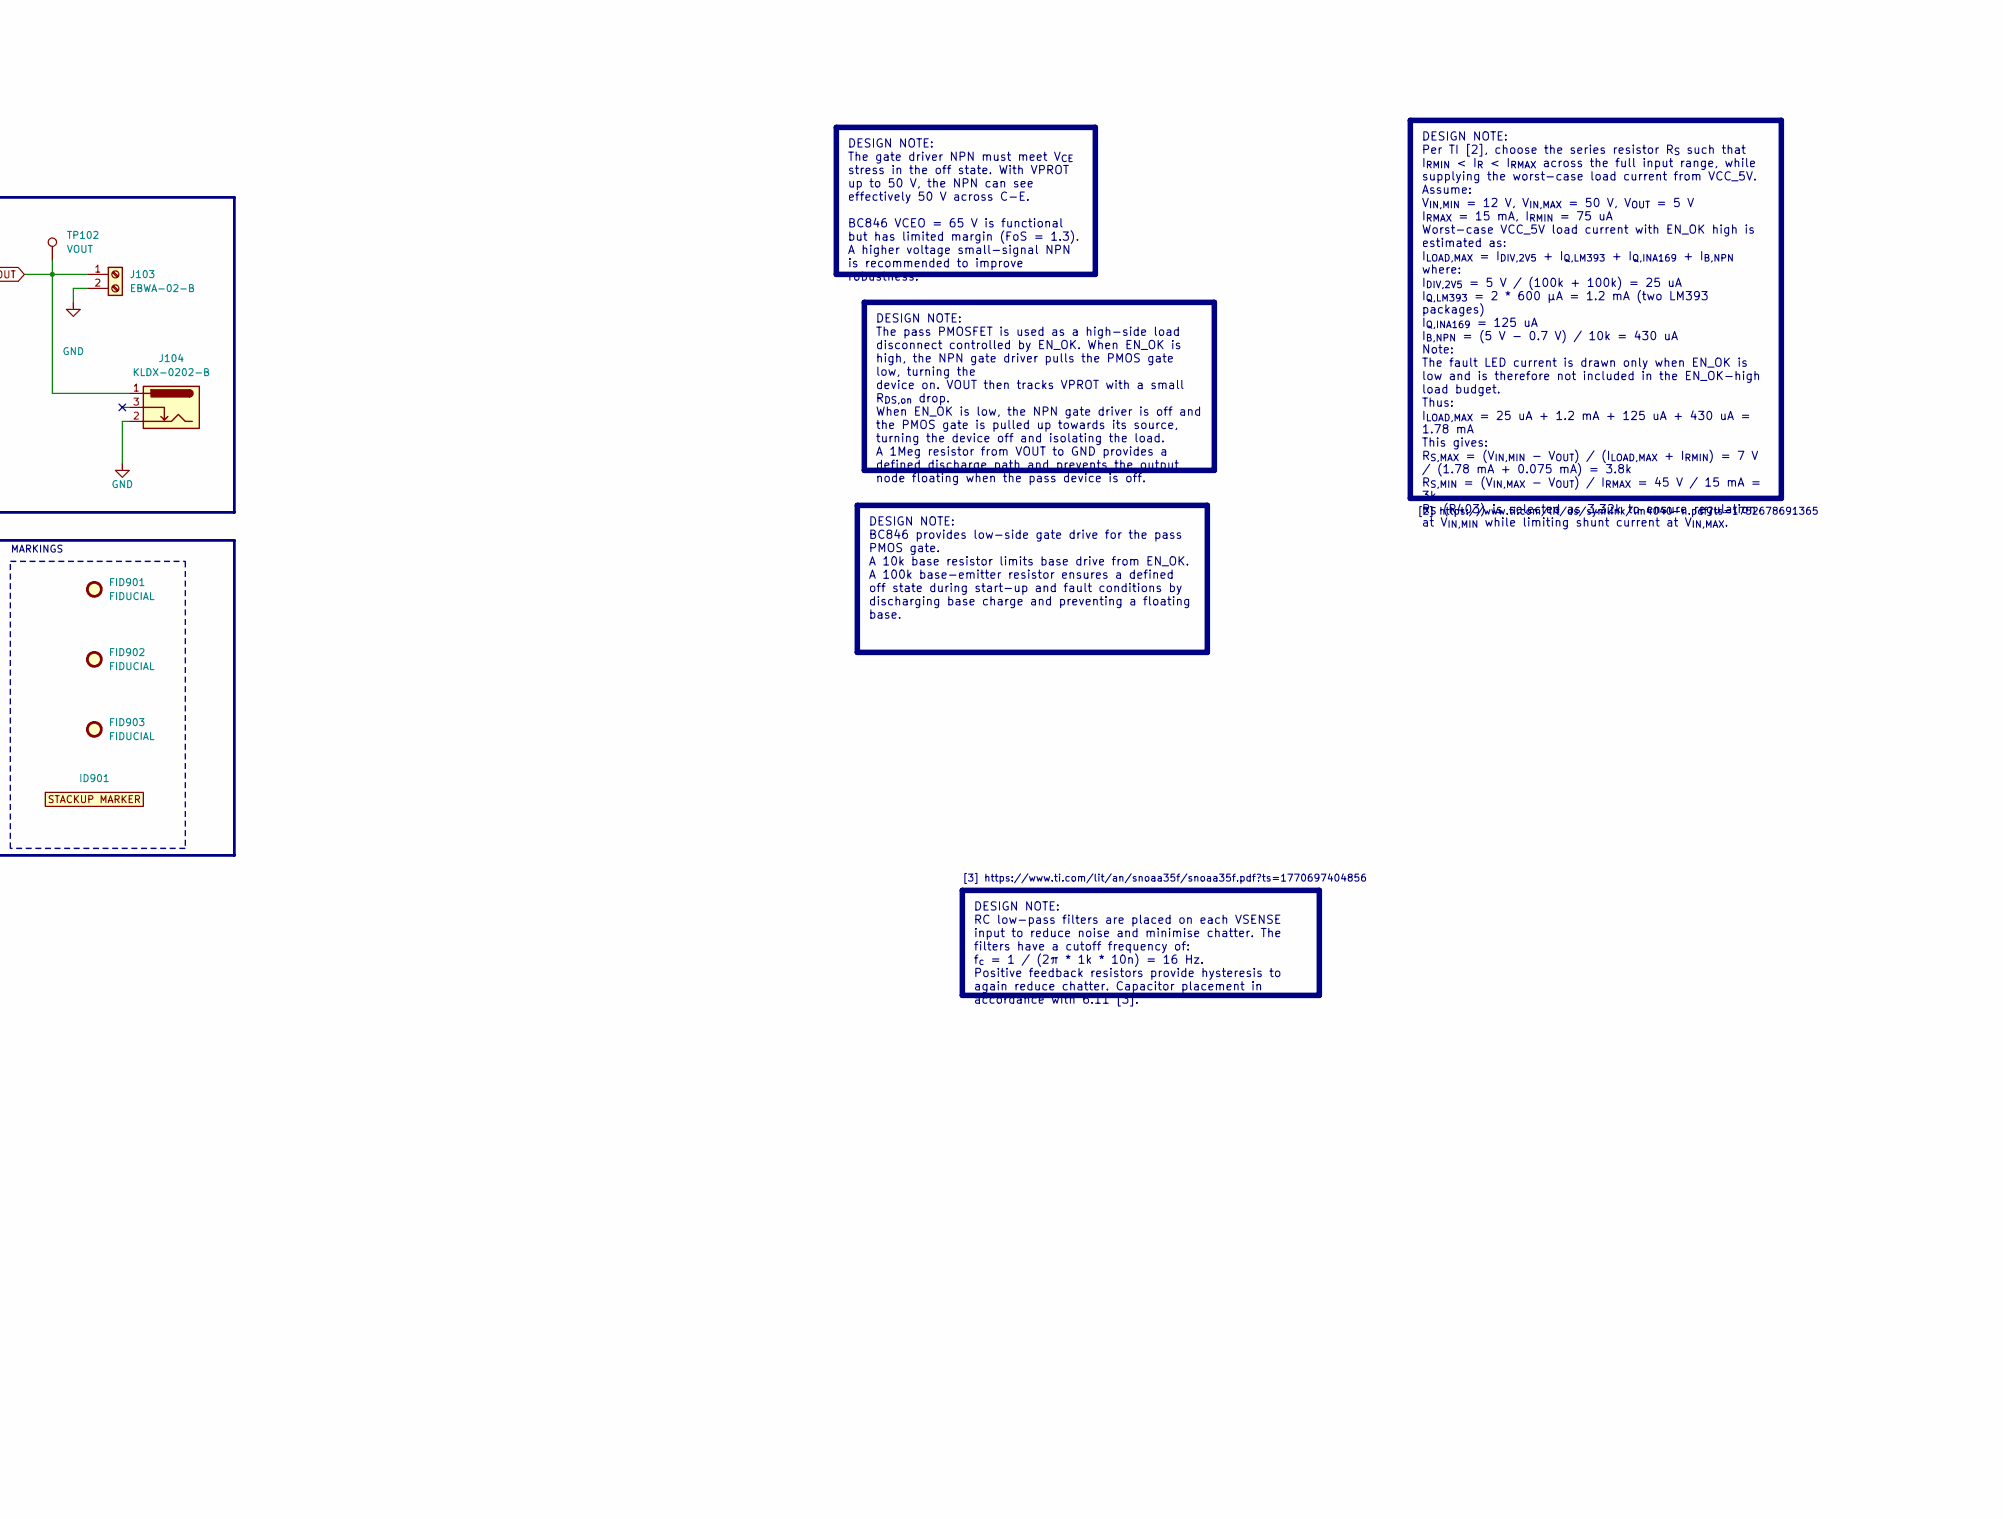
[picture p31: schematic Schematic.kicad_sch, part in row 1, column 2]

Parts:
C301, C403, C505, C601, C701: 100n; C_0603_1608Metric; Voltage_Rating 16V; Tolerance 10%; MPN C1608X7R1C104KT
C302, C502, C504: 1u; C_0603_1608Metric; Voltage_Rating 6.3V; Tolerance 10%; MPN C1608X5R0J105KT
C303, C401, C402, C501: 10n; C_0603_1608Metric; Voltage_Rating 50V; Tolerance 10%; MPN C1608X7R1H103KT
C503: 4.7u; C_0603_1608Metric; Voltage_Rating 6.3V; Tolerance 10%; MPN C1608X5R0J475MT
D201, D701: D3Z10BF-7; D_SOD-323; MPN D3Z10BF-7
D301: MM3Z5V6; D_SOD-323; MPN MM3Z5V6
D501, D502: 1N4148WS; D_SOD-323; MPN 1N4148WS
D801: LED; LED_0805_2012Metric; MPN LTST-C170KRKT
D802: LED; LED_0805_2012Metric; MPN LTST-C170KGKT
FID901, FID902, FID903: FIDUCIAL; Fiducial_1mm_Mask2mm
H901, H902, H903, H904: MOUNT_M2.5; MountingHole_2.7mm_M2.5_ISO7380_Pad
ID901: BOARD_STACKUP_MARKER; STACKUP_ID_2L
J101, J104: KLDX-0202-B; BarrelJack_Kycon_KLDX-0202-xC_Horizontal; MPN KLDX-0202-B
J102, J103: EBWA-02-B; TerminalBlock_Phoenix_MKDS-1-2-3.81_1x02_P3.81mm_Horizontal; MPN EBWA-02-B
Q201, Q702: MCU18P10Y-TP; DPAK_MCC; MPN MCU18P10Y-TP
Q301, Q701, Q802: BC846; SOT-23; MPN BC846
Q501, Q801: BC856; SOT-23
R201, R202, R302, R406, R509, R511, R703, R704: 100k; R_0603_1608Metric; Tolerance 1%
R301: 12.1k; R_1206_3216Metric; Tolerance 1%
R303, R602: 33.2k; R_0603_1608Metric; Tolerance 1%
R304: 332k; R_0603_1608Metric; Tolerance 1%
R305, R505: 49.9k; R_0603_1608Metric; Tolerance 1%
R306, R502: 121k; R_0603_1608Metric; Tolerance 1%
R401: 22.1k; R_0603_1608Metric; Tolerance 1%
R402: 200k; R_0603_1608Metric; Tolerance 1%
R403, R404, R504, R510: 1k; R_0603_1608Metric; Tolerance 1%
R405, R506, R507, R603, R702: 10k; R_0603_1608Metric; Tolerance 1%
R501: 357k; R_0603_1608Metric; Tolerance 1%
R503: 30.1k; R_0603_1608Metric; Tolerance 1%
R508: 432k; R_0603_1608Metric; Tolerance 1%
R601: 18.2k; R_0603_1608Metric; Tolerance 1%
R701: 20m; R_2512_6332Metric; Tolerance 1%; MPN WSL2512R0200FEA
R705: 15k; R_0603_1608Metric; Tolerance 1%
R801, R802: 2.49k; R_0603_1608Metric; Tolerance 1%
TP101: VIN; TestPoint_Pad_D1.0mm
TP102: VOUT; TestPoint_Pad_D1.0mm
TP201: VPROT; TestPoint_Pad_D1.0mm
TP301: VCC; TestPoint_Pad_D1.0mm
TP302: VREF_5V; TestPoint_Pad_D1.0mm
TP501: OC_PK; TestPoint_Pad_D1.0mm
TP701: SYS_OK; TestPoint_Pad_D1.0mm
TP702: V_I; TestPoint_Pad_D1.0mm
TP901: GND; TestPoint_Pad_1.0x1.0mm
U301: LM4040N-5.0; SOT-23; Tolerance 0.5%; MPN LM4040CIM3-5.0/NOPB
U401, U501, U601: LM393; SOIC-8_3.9x4.9mm_P1.27mm
U701: INA169NA/3K; SOT-23-5; MPN INA169NA/3K

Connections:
/SCHEMATIC/B_PRCHRG: C504.1, Q501.1 (B), R511.2
/SCHEMATIC/CAP_PRCHRG: Q501.3 (C), R510.1
/SCHEMATIC/GATE_P: D701.2 (A), Q701.3 (C), Q702.1, R704.2
/SCHEMATIC/GATE_RPP: D201.2 (A), Q201.1, R201.1, R202.1
/SCHEMATIC/I_SENSE_1A: C502.1, R505.1, U501.6 (-)
/SCHEMATIC/I_SENSE_PEAK: C501.1, R504.1, U501.2 (-)
/SCHEMATIC/LED_FAULT: D801.2 (A), R801.2
/SCHEMATIC/LED_OK: D802.2 (A), R802.2
/SCHEMATIC/OC_1A_FAULT: D502.1 (K), R507.1, U501.7
/SCHEMATIC/OC_1A_REF: R502.1, R503.2, U501.5 (+)
/SCHEMATIC/OC_LOCKOUT: C503.1, D501.2 (A), D502.2 (A), R508.1, R509.2, R510.2
/SCHEMATIC/OC_LOCKOUT_REF: R601.1, R602.2, U601.2 (-)
/SCHEMATIC/OC_PEAK_FAULT: D501.1 (K), R506.1, TP501.1, U501.1
/SCHEMATIC/OC_PEAK_REF: R501.1, R502.2, U501.3 (+)
/SCHEMATIC/VZ: C301.2, D301.1 (K), Q301.1 (B), R301.1, R302.1
/SCHEMATIC/V_SENSE: R401.2, R402.1, R403.2, R404.2
/SCHEMATIC/V_SENSE_OV: C402.2, R404.1, U401.6 (-)
/SCHEMATIC/V_SENSE_UV: C401.2, R403.1, U401.3 (+)
GND: C301.1, C302.2, C303.2, C401.1, C402.1, C403.2, C501.2, C502.2, C503.2, C504.2, C505.2, C601.2, C701.1, D301.2 (A), D801.1 (K), H901.1, H902.1, H903.1, H904.1, J101.2, J102.2, J103.2, J104.2, Q701.2 (E), Q802.2 (E), R201.2, R306.1, R401.1, R503.1, R602.1, R703.1, R705.1, TP901.1, U301.2 (A), U401.4 (V-), U501.4 (V-), U601.4 (V-), U601.5 (+), U601.6 (-), U701.2 (GND)
unnamed: D802.1 (K), Q802.3 (C)
unnamed: Q701.1 (B), R702.1, R703.2
unnamed: Q801.3 (C), R801.1
OC_FAULT: Q801.1 (B), R509.1, U601.3 (+)
OV_REF: R304.2, R305.2, U401.5 (+)
SYS_OK: R405.1, R406.2, R603.1, R702.2, TP701.1, U401.1, U401.7, U601.1
UV_REF: R305.1, R306.2, U401.2 (-)
VCC: C302.1, C403.1, C505.1, C601.1, C701.2, Q301.2 (E), Q501.2 (E), Q801.2 (E), R302.2, R405.2, R506.2, R507.2, R508.2, R511.1, R603.2, R802.1, TP301.1, U401.8 (V+), U501.8 (V+), U601.8 (V+), U701.5 (V+)
VIN: J101.1, J102.1, Q201.2, TP101.1
VOLTAGE_OK: Q802.1 (B), R406.1
VOUT: J103.1, J104.1, Q702.2, TP102.1
VPROT: D201.1 (K), Q201.3, Q301.3 (C), R202.2, R301.2, R303.2, R402.2, R701.1, TP201.1, U701.3 (+)
VREF_5V: C303.1, R303.1, R304.1, R501.2, R601.2, TP302.1, U301.1 (K)
VSUPPLY: D701.1 (K), Q702.3, R701.2, R704.1, U701.4 (-)
V_I: R504.2, R505.2, R705.2, TP702.1, U701.1

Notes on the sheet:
SHUNT
[1] https://www.ti.com/lit/an/slvae57b/slvae57b.pdf?ts=1770319054914
~1mA
OV AND UV REF
CAPACITOR PRE-CHARGER
6. OVERCURRENT LOCKOUT
[3] https://www.ti.com/lit/an/snoaa35f/snoaa35f.pdf?ts=1770697404856
IC POWER
8. HMI
3. VCC AND VREF
1.207V
2. REVERSE POLARITY PROTECTION
4. UNDERVOLTAGE AND OVERVOLTAGE DETECTION
[2] https://www.ti.com/lit/ds/symlink/lm4040-n.pdf?ts=1752678691365
0.297V
VREF
VCC
1. INTERCONNECTS
1.704V
VSENSE ÷10
7. SHUNT AND PASS ELEMENT
1.492V
5.024V
4.6V
5. OVERCURRENT DETECTION
MOUNTING
MARKINGS
9. MOUNTING AND MARKINGS
[${#}] ${TITLE}
DESIGN NOTE: The pass PMOSFET is used as a high-side load disconnect controlled by EN_OK. When EN_OK is high, the NPN gate driver pulls the PMOS gate low, turning the device on. VOUT then tracks VPROT with a small R_{DS,on} drop. When EN_OK is low, the NPN gate driver is off and the PMOS gate is pu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
DESIGN NOTE: The over-current trip points are 1A and 5A, with 20m shunt. At 1A, V_{SHUNT} = I * R_{SHUNT} = 1A * 20m = 20mV At 5A, V_{SHUNT} = I * R_{SHUNT} = 5A * 20m = 100mV
DESIGN NOTE: The gate driver NPN must meet V_{CE} stress in the off state. With VPROT up to 50 V, the NPN can see effectively 50 V across C-E. BC846 VCEO = 65 V is functional but has limited margin (FoS = 1.3). A higher voltage small-signal NPN is recommended to improve robustness.
DESIGN NOTE: BC846 provides low-side gate drive for the pass PMOS gate. A 10k base resistor limits base drive from EN_OK. A 100k base-emitter resistor ensures a defined off state during start-up and fault conditions by discharging base charge and preventing a floating base.
DESIGN NOTE: This PMOS is acting as an ideal diode [1]. A 10 V zener from gate to source limits V_{GS} ≤ 10 V under all VIN and transient conditions to protect the PMOS. A 100k gate to source resistor stops the gate floating. A 100k gate pulldown resistor sets default state to OFF when no voltage a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
LAYOUT NOTE: We'll size for 5A current on 35um trace. We'll pick 3.5mm for a 25% margin. Keep traces short and wide, use pours/puddles when possible.
DESIGN NOTE: Current is measured using INA169 with R_{SHUNT} = 20m. With R_{L} = 15k, the output voltage is: V_{OUT} = I * R_{SHUNT} * (R_{L} / 1k) At 1A: V_{OUT} = 1A * 20m * (15k / 1k) = 0.30V At 5A: V_{OUT} = 5A * 20m * (15k / 1k) = 1.50V
DESIGN NOTE: The lockout delay is set by an RC network with R = 432k and C = 4.7u. The time constant is: τ = R * C ≈ 432k * 4.7u ≈ 2s After a fault the capacitor must recharge before the circuit rearms, creating a ~2s lockout period.
DESIGN NOTE: A capacitor pre-charge diode rapidly charges the timing capacitor at startup, ensuring the lockout circuit begins in the armed state and preventing a false startup delay.
LAYOUT NOTE: Route HI LO leads short from shunt to current amplifier.
DESIGN NOTE: Per TI [2], choose the series resistor R_{S} such that I_{RMIN} < I_{R} < I_{RMAX} across the full input range, while supplying the worst-case load current from VCC_5V. Assume: V_{IN,MIN} = 12 V, V_{IN,MAX} = 50 V, V_{OUT} = 5 V I_{RMAX} = 15 mA, I_{RMIN} = 75 uA Worst-case VCC_5V load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

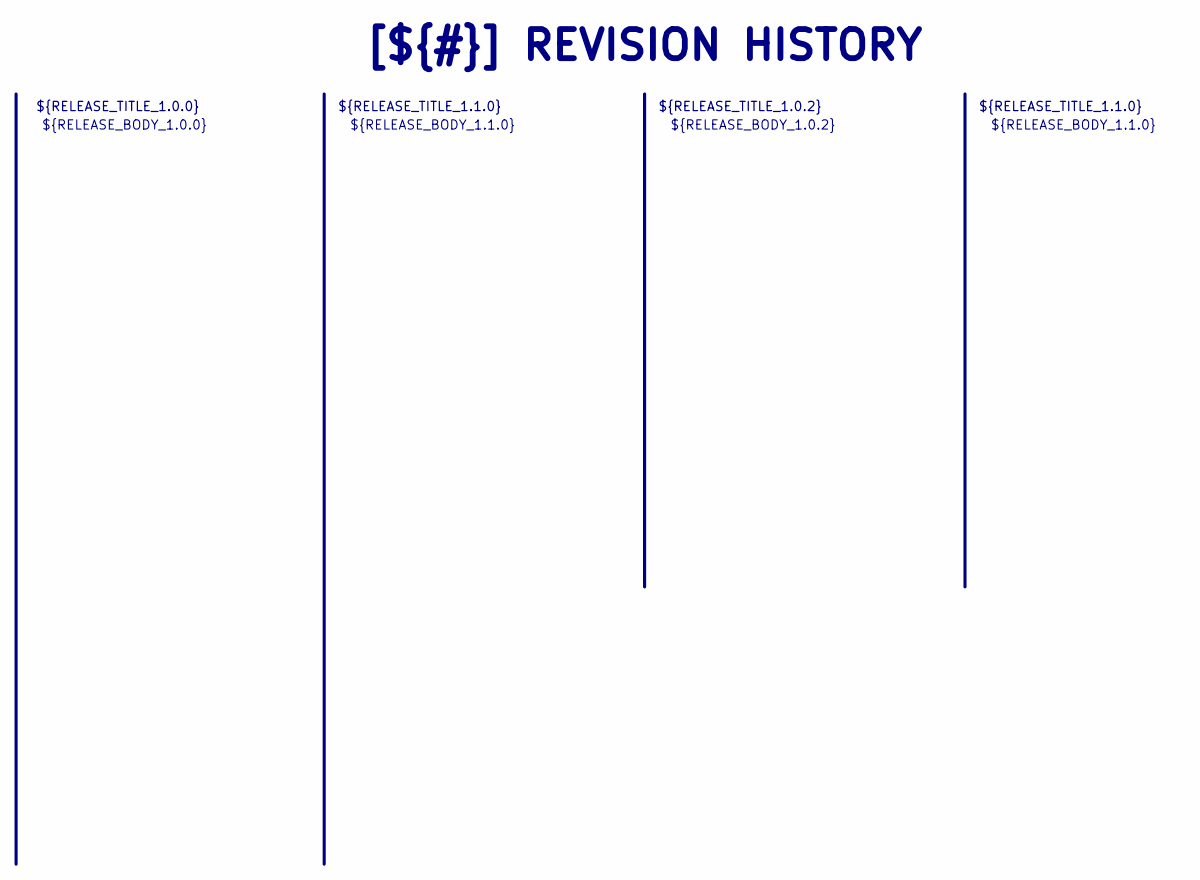
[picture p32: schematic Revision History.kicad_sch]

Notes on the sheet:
${RELEASE_BODY_1.1.0}
[${#}] ${TITLE}
${RELEASE_BODY_1.0.0}
${RELEASE_TITLE_1.0.2}
${RELEASE_BODY_1.0.2}
${RELEASE_TITLE_1.0.0}
${RELEASE_TITLE_1.1.0}

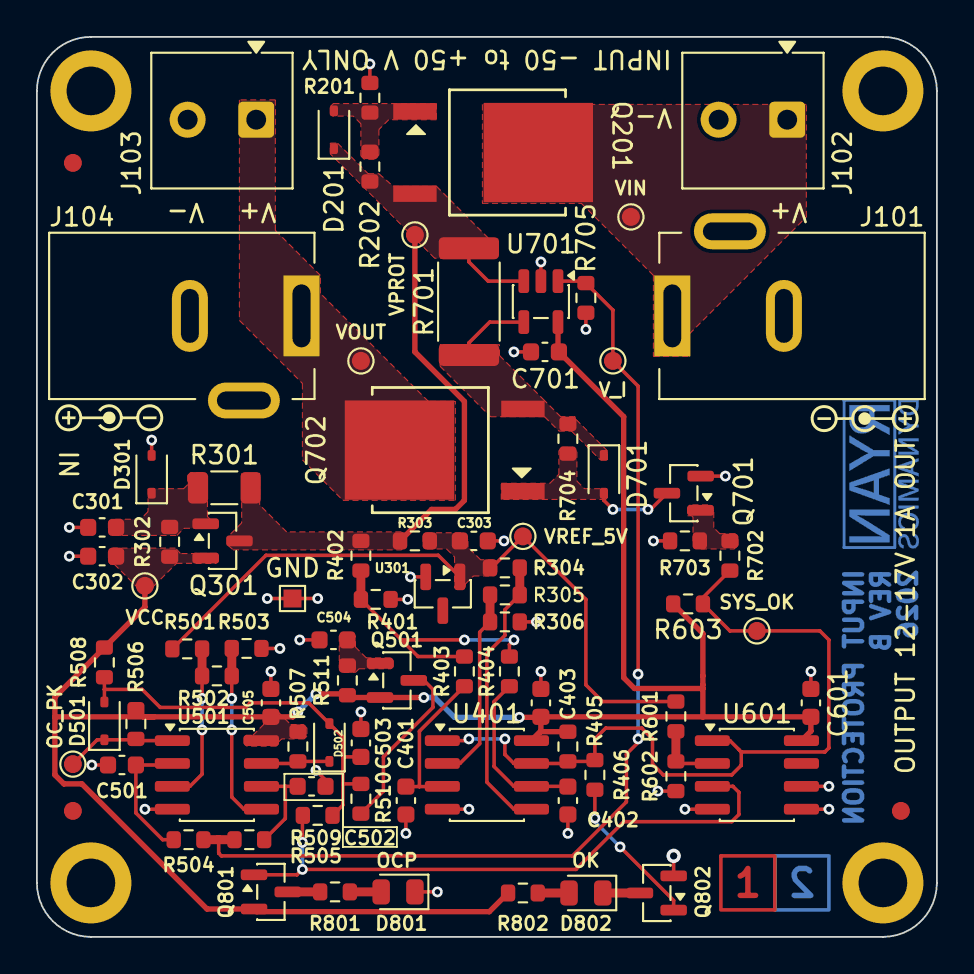
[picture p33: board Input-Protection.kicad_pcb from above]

Board: 2 copper layers, 50.0 x 50.0 mm, 88 parts (0 on the bottom side), 34 nets.

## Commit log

2026-02-18 feat: initial commit, assignment 1 base design to be improved
    [Block Diagram.kicad_sch, Comparator.kicad_sch, Input-Protection-(L1-L2)_drill_table.csv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]
2026-03-06 feat: pcb mvp
    [Input-Protection.kicad_pcb, Input-Protection.kicad_sch, Schematic.kicad_sch]
2026-03-06 Update Outputs (release)
    [Input-Protection-(L1-L2)_drill_table.csv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]
